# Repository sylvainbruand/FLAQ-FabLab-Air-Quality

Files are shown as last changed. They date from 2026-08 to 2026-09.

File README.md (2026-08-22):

# FLAQ XIAO — FabLab Air Quality

Projet académique de contrôle de la qualité de l’air dans les FabLabs, réalisé
avec une **Seeed Studio XIAO ESP32S3**. La carte acquiert les
capteurs, affiche les mesures sur OLED, enregistre l’historique sur microSD et
héberge elle-même un dashboard accessible depuis un téléphone ou un ordinateur.

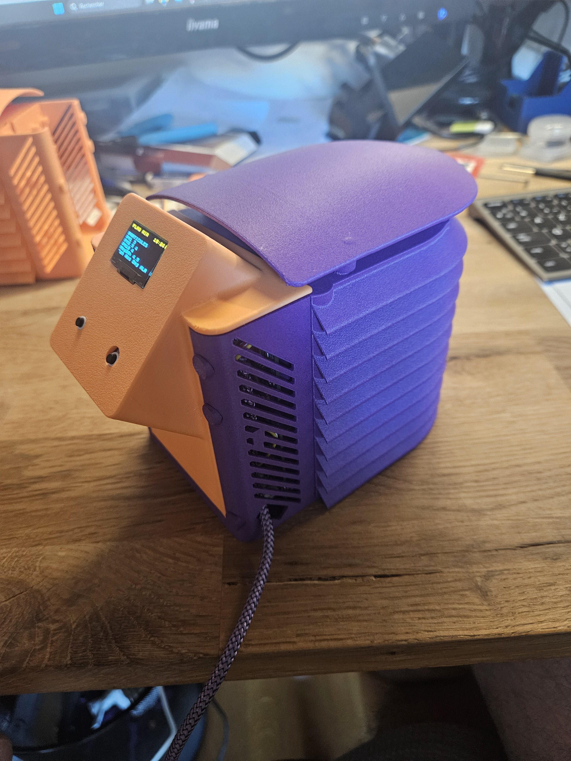
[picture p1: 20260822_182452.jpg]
Prototype FLAQ XIAO assemblé


## Fonctions incluses

- actualisation des mesures toutes les 10 secondes ;
- lecture du SGP40 toutes les secondes avec compensation DHT20 ;
- trois graphiques avec axes indépendants ;
- moyenne glissante PM2.5 sur 24 heures ;
- indice intérieur FLAQ du vert au rouge ;
- alarme confirmée sur buzzer passif au niveau rouge ;
- journal persistant des dépassements avec durée, moyenne et maximum ;
- synthèse quotidienne et export CSV depuis le dashboard ;
- horodatage par RTC Grove PCF85063 ;
- correction NTP automatique lorsque le réseau donne accès à Internet ;
- point d’accès `FLAQ-XIAO` si aucun Wi-Fi n’est configuré ou disponible ;
- reprise de l’historique des dernières 24 heures après redémarrage ;
- navigation manuelle entre les quatre pages OLED avec le bouton Grove ;
- extinction de l’OLED après 20 secondes sans appui et réveil automatique ;
- déclaration manuelle d’une ventilation avec un second bouton Grove ;
- signalement de la ventilation sur le dashboard ;
- bandes temporelles claires sur les graphes pendant les périodes ventilées.

## Matériel

| Fonction | Référence | Connexion |
|---|---|---|
| Carte | Seeed Studio XIAO ESP32S3 | — |
| Hub | Grove 8-Channel I²C Hub TCA9548A | `D4/SDA`, `D5/SCL`, adresse `0x70` |
| CO₂ | SCD30 | I²C `0x61` |
| Particules | HM3301 | I²C `0x40` |
| VOC | SGP40 | I²C `0x59` |
| HCHO indicatif | Grove HCHO WSP2110 | analogique `D0`, via pont diviseur |
| Température/humidité | DHT20 | I²C `0x38` |
| Horloge | RTC Grove PCF85063 | I²C `0x51` |
| Affichage | OLED SSD1306 128×64 | I²C `0x3C` |
| Alarme | Grove Passive Buzzer 107020109 | `D1` |
| Navigation OLED | Grove Button (P) 111020000 | port `D7 / UART` |
| Ventilation | Grove Button (P) 111020000 | port `D0 / A0` |
| Stockage | Adafruit MicroSD Breakout+ 254 | SPI, CS sur `D2` |

Le câblage détaillé se trouve dans
[ease_xiao/CABLAGE.md](ease_xiao/CABLAGE.md).

Au démarrage, le firmware ouvre automatiquement les huit canaux du TCA9548A.
Cette configuration est possible car chaque capteur utilise une adresse I²C
différente. Elle se règle avec `EASE_I2C_MUX_*` dans `config.example.h`.

## Préparation de l’Arduino IDE

1. Installer le paquet de cartes **esp32 by Espressif Systems**.
2. Sélectionner **XIAO_ESP32S3**.
3. Activer la PSRAM en mode **OPI PSRAM**.
4. Sélectionner une taille Flash de **8 MB**.
5. Installer les bibliothèques :
   - U8g2 ;
   - Adafruit SGP40 Sensor, avec ses dépendances ;
   - SparkFun SCD30 Arduino Library ;
   - DHT20 de Rob Tillaart.

Le HM3301 est lu directement par le firmware via `Wire`, afin d’éviter
l’incompatibilité du type `u32` présente dans la bibliothèque Seeed 1.0.2 avec
les versions ESP32 récentes. En cas de trame incomplète ou de checksum invalide,
la lecture est retentée trois fois et le capteur est automatiquement replacé en
mode I2C. Les concentrations utilisées sont les valeurs « environnement
atmosphérique » du HM3301.

Les bibliothèques `WiFi`, `WebServer`, `ESPmDNS`, `SD`, `SPI` et `Wire` sont
fournies par le paquet ESP32.

## Configuration Wi-Fi

Le projet fonctionne immédiatement sans identifiants : la carte crée le réseau
`FLAQ-XIAO`, protégé par le mot de passe `flaq-air`. Une fois connecté à ce
réseau, ouvrir `http://192.168.4.1`.

Pour connecter la station au réseau local :

1. copier `config.h.example` sous le nom `config.h` ;
2. renseigner le nom et le mot de passe Wi-Fi ;
3. téléverser à nouveau le programme.

Le dashboard devient alors accessible à l’adresse IP affichée sur l’OLED et,
si le réseau l’autorise, à `http://flaq-xiao.local`.

`config.h` est ignoré par Git pour ne pas publier le mot de passe.

## Carte microSD

Utiliser une microSD High Endurance de 32 Go formatée en FAT32. La station crée :

- `/data/AAAAMMJJ.csv` : mesures d’une journée ;
- `/events.csv` : dépassements terminés.

La fenêtre glissante est maintenue en PSRAM. Au redémarrage, les fichiers du
jour courant et du jour précédent sont relus afin de reconstruire les dernières
24 heures, la moyenne PM2.5 et les périodes de ventilation. La colonne
`ventilation` vaut `1` lorsque la fenêtre ou la porte a été déclarée ouverte.

## Seuils

Tous les seuils se trouvent dans `config.example.h` et peuvent être redéfinis
dans `config.h`. L’indice global correspond au paramètre instantané le plus
défavorable parmi CO₂, VOC, HCHO estimé, PM2.5 et PM10.

Une alerte ou un événement nécessite trois mesures consécutives au-dessus du
seuil. Le retour utilise un seuil plus bas et trois confirmations, ce qui évite
les oscillations autour d’une limite.

Le seuil de la moyenne PM2.5 sur 24 heures produit un événement distinct. Il
n’est activé que lorsque la station dispose d’au moins 23 heures d’historique.

Ces seuils constituent un indicateur pédagogique FLAQ de qualité de l’air
intérieur ; ils ne remplacent pas un dispositif réglementaire ou certifié.

## Particularités du WSP2110

Le WSP2110 est désactivé par défaut avec `EASE_WSP2110_ENABLED 0`. Dans cet
état, D0 n'est pas lu, le dashboard affiche « non installé », le HCHO est
ignoré par l'indice et aucune alerte HCHO n'est créée. Quand le capteur et son
pont diviseur sont prêts, définir `EASE_WSP2110_ENABLED 1` dans `config.h`.

Le WSP2110 est un capteur MOS sensible à plusieurs gaz et solvants. La valeur
« HCHO estimé » en ppm sert donc à suivre une tendance après étalonnage ; ce
n’est pas une mesure sélective ou certifiée du formaldéhyde. Le capteur demande
au moins 120 heures de préchauffage avant son étalonnage initial.

Le module Grove fonctionne en 5 V alors que l’entrée analogique du XIAO est en
3,3 V. Sa sortie doit obligatoirement passer par le pont 10 kΩ / 20 kΩ décrit
dans `ease_xiao/CABLAGE.md`. La constante `EASE_WSP2110_R0_RATIO` doit ensuite
être ajustée dans `config.h` avec la valeur obtenue en air propre stabilisé. Le
moniteur série affiche `WSP_Rs` et `ADC` pour faciliter cette opération.

## API embarquée

| Route | Rôle |
|---|---|
| `/` | dashboard |
| `/logo.png` | logo FLAQ et favicon |
| `/api/live` | dernière mesure et état technique |
| `/api/history?since=...&max=900` | historique sous-échantillonné |
| `/api/events?max=200` | journal des dépassements |
| `/api/events.csv` | téléchargement CSV |
| `/api/health` | mémoire et disponibilité du serveur |

## Organisation du dépôt

- [`ease_xiao/`](ease_xiao/) : station autonome XIAO ESP32S3 ;
- [`ease_station_test/`](ease_station_test/) : versions précédentes et station de test.

## Fichiers du projet XIAO

- `ease_xiao/ease_xiao.ino` : firmware complet ;
- `ease_xiao/dashboard.h` : interface web embarquée sans dépendance Internet ;
- `ease_xiao/config.example.h` : valeurs par défaut et seuils ;
- `ease_xiao/config.h.example` : modèle de configuration Wi-Fi ;
- `ease_xiao/CABLAGE.md` : raccordement pas à pas ;
- `ease_xiao/VERIFICATION.md` : procédure de mise en service.

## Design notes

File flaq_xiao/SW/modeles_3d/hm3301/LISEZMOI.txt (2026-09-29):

Modèle d'encombrement Grove HM3301 — Seeed v1.0

Sources :
https://wiki.seeedstudio.com/Grove-Laser_PM2.5_Sensor-HM3301/
Archive Eagle officielle conservée dans sources_seeed.zip.
Fiche HM-3300&3600_V2.1.pdf, dimensions du capteur : 40 x 38 x 15 mm.

Données issues du fichier Eagle : carte 80 x 40 mm, angles R3, quatre trous diamètre 3,2 mm aux coordonnées (+/-36,+/-16) ; trous de fixation capteur diamètre 2,4 mm à (-23,622,-17,018) et (12,573,17,145). Positions des composants et connecteurs issues du PCB.

Hypothèses à vérifier : PCB épaisseur 1,6 mm ; dessous capteur à 3,6 mm du dessous PCB ; hauteurs des connecteurs et composants ; grilles, capot, dégagements et vis simplifiés. Câble souple non représenté. Ne pas utiliser les grilles comme plan de fabrication ou pour une simulation de débit.

Pièce native SolidWorks 2025, fonctions éditables. Unités géométriques : mm (API en mètres). Fichier destiné à l'intégration mécanique ; contrôler les hauteurs sur l'exemplaire physique avant fabrication.

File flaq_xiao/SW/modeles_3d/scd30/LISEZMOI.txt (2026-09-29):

Grove SCD30 — modèle SolidWorks 2025

Sources :
https://wiki.seeedstudio.com/Grove-CO2_Temperature_Humidity_Sensor-SCD30/
https://sensirion.com/media/documents/E9438033/61653143/Sensirion_CO2_Sensors_SCD30_POD_STEP_File.zip

Capteur nu : 25 corps importés du STEP officiel Sensirion, sans modification de forme. Position de montage estimée.
Carte : contour et perçages issus du package GROVE-60X40MM du fichier Eagle Seeed. Débordements des oreilles compris : environ 64,2 x 44,2 mm, différents des dimensions générales 61 x 42 mm affichées au wiki. Le contour du fichier CAO est retenu. Epaisseur PCB supposée 1,6 mm.
Capot : contour repris du dessin de sérigraphie Seeed ; hauteur, épaisseur, ouvertures et vis simplifiées/estimées. Hauteur totale fixée à 19 mm selon la fiche générale. Connecteur Grove placé selon Eagle ; hauteur simplifiée.

Pièce mult icorps native SLDPRT : formes importées Sensirion et fonctions éditables pour la carte, le connecteur et le capot. Aucune dépendance externe nécessaire à l'ouverture du SLDPRT. Vérifier les dimensions de votre révision physique avant fabrication d'un boîtier.

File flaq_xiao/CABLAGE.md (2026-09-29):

# Câblage de la station FLAQ XIAO

## Bus I²C Grove

Raccorder le Grove 8-Channel I²C Hub TCA9548A au port I²C du Grove Shield XIAO :

- SDA : `D4 / GPIO5` ;
- SCL : `D5 / GPIO6` ;
- alimentation et masse communes.

Brancher ensuite sur le hub : SCD30, HM3301, SGP40, DHT20, OLED et RTC
PCF85063. Leurs adresses sont différentes ; aucun multiplexeur logiciel n’est
nécessaire par capteur. Le firmware écrit `0xFF` à l’adresse `0x70` au démarrage
pour ouvrir simultanément les huit canaux du TCA9548A.

La longueur totale des câbles I²C doit rester raisonnable. Le firmware utilise
100 kHz pour améliorer la robustesse avec plusieurs modules.

## Buzzer Grove 107020109

Brancher le buzzer passif sur le port numérique correspondant à `D1`. Le
firmware produit une tonalité de 2 700 Hz lorsque l’indice rouge est confirmé.

## Grove Dual Button sur D7 / UART

Raccorder le Grove Dual Button au connecteur marqué `D7 / UART` du shield
XIAO. Les deux lignes de signal de cette prise sont utilisées :

| Signal Grove | XIAO ESP32S3 | Fonction |
|---|---|---|
| jaune / SIG1 | `D7` | bouton de changement de page |
| blanc / SIG2 | `D6` | bouton de ventilation |
| rouge | `3,3 V` | alimentation du Dual Button |
| noir | `GND` | masse |

Le bouton sur D7 fait avancer d’une page et la quatrième page revient à la première.
L’écran s’éteint après 20 secondes sans appui ; l’appui suivant le rallume et
affiche directement la page suivante. Le filtrage anti-rebond est intégré au
firmware.

Le bouton sur D6 inverse l’état : ventilation active, puis ventilation arrêtée.
Un appui simultané sur les deux boutons active ou désactive le mode muet.
Les sorties du module sont actives à l’état bas ; le firmware active aussi les
résistances de tirage internes de la XIAO.

Le Dual Button doit être alimenté ici en 3,3 V afin que ses niveaux hauts restent
sans danger pour la XIAO. Ne jamais envoyer directement un signal 5 V sur D6 ou
D7. Ce raccordement laisse `D0 / A0` entièrement disponible pour le WSP2110.

## Grove HCHO WSP2110 — entrée analogique protégée

Le WSP2110 n’est pas raccordé au hub I²C. Alimenter son module Grove en 5 V et
relier toutes les masses. Sa sortie analogique peut dépasser 3,3 V : ne jamais
la brancher directement sur `D0` du XIAO.

Réaliser ce pont diviseur :

```text
Sortie SIG du WSP2110 ── 10 kΩ ──┬── D0 du XIAO
                                  │
                                 20 kΩ
                                  │
                                 GND
```

Ajouter de préférence un condensateur céramique de 100 nF entre `D0` et GND,
au plus près du XIAO. Le rapport du pont est alors 2/3, valeur déjà définie par
`FLAQ_WSP2110_DIVIDER_RATIO`. Vérifier au multimètre que D0 reste toujours sous
3,3 V avant de le connecter à la carte.

Le firmware accepte que le WSP2110 ne soit pas installé : D0 peut rester non
connecté, le démarrage continue normalement et la valeur HCHO reste indiquée
comme indisponible jusqu’à la première lecture valide. Un bref test logiciel
compare les résistances de tirage vers la masse et vers le 3,3 V afin d’empêcher
une entrée D0 flottante d’être prise par erreur pour un capteur présent. Trois
lectures valides consécutives sont ensuite nécessaires pour publier le HCHO.

## Module microSD Adafruit 254

| Adafruit 254 | XIAO ESP32S3 | Fonction |
|---|---|---|
| `5V` | `5V/VBUS` | alimentation du régulateur du module |
| `GND` | `GND` | masse commune |
| `CLK` | `D8 / GPIO7` | horloge SPI |
| `DO` | `D9 / GPIO8` | MISO |
| `DI` | `D10 / GPIO9` | MOSI |
| `CS` | `D2 / GPIO3` | sélection de la carte |

Le raccordement `5V/VBUS` suppose une alimentation USB 5 V. Pour une station
alimentée uniquement par batterie, vérifier que le rail 5 V reste disponible
ou prévoir une alimentation adaptée pour le module microSD et les capteurs.

## Alimentation

Le HM3301 et le SCD30 contiennent des éléments actifs et le HM3301 possède un
ventilateur. Employer une alimentation USB 5 V stable, avec une marge de
courant suffisante. Toutes les masses doivent être communes.

Ne jamais appliquer un signal ou une tension analogique 5 V directement aux GPIO de la XIAO.
L’Adafruit 254 réalise l’adaptation nécessaire pour la microSD.

## Implantation des capteurs

- éloigner le DHT20 de la chaleur produite par la XIAO et le régulateur ;
- ne pas placer les entrées d’air du SCD30, du HM3301 et du WSP2110 contre une paroi ;
- éviter que la sortie d’air du HM3301 souffle directement sur le DHT20 ;
- laisser le SGP40 exposé au même volume d’air que les autres capteurs ;
- éloigner le WSP2110 des vapeurs de solvants et garder son module sous tension
  au moins 120 heures avant l’étalonnage initial ;
- conserver le buzzer et l’OLED hors du trajet principal de l’air.

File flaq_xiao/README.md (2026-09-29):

# FLAQ XIAO — FabLab Air Quality

Projet académique de contrôle de la qualité de l’air dans les FabLabs, réalisé
avec une **Seeed Studio XIAO ESP32S3**. La carte acquiert les
capteurs, affiche les mesures sur OLED, enregistre l’historique sur microSD et
héberge elle-même un dashboard accessible depuis un téléphone ou un ordinateur.

## Fonctions incluses

- actualisation des mesures toutes les 10 secondes ;
- lecture du SGP40 toutes les secondes avec compensation DHT20 ;
- trois graphiques avec axes indépendants ;
- moyenne glissante PM2.5 sur 24 heures ;
- indice intérieur FLAQ du vert au rouge ;
- alarme confirmée sur buzzer passif au niveau rouge ;
- journal persistant des dépassements avec durée, moyenne et maximum ;
- synthèse quotidienne et export CSV depuis le dashboard ;
- horodatage par RTC Grove PCF85063 ;
- correction NTP automatique lorsque le réseau donne accès à Internet ;
- point d’accès `FLAQ-XIAO` si aucun Wi-Fi n’est configuré ou disponible ;
- reprise de l’historique des dernières 24 heures après redémarrage.
- navigation manuelle entre les quatre pages OLED avec le bouton Grove ;
- extinction de l’OLED après 20 secondes sans appui et réveil automatique.
- déclaration manuelle d’une ventilation avec un second bouton Grove ;
- mode mute basculé en appuyant sur les deux boutons en même temps ;
- signalement de la ventilation sur le dashboard et éclaircissement des graphes.
- bandes temporelles claires sur les graphes pendant les périodes ventilées.

## Matériel

| Fonction | Référence | Connexion |
|---|---|---|
| Carte | Seeed Studio XIAO ESP32S3 | — |
| Hub | Grove 8-Channel I²C Hub TCA9548A | `D4/SDA`, `D5/SCL`, adresse `0x70` |
| CO₂ | SCD30 | I²C `0x61` |
| Particules | HM3301 | I²C `0x40` |
| VOC | SGP40 | I²C `0x59` |
| HCHO indicatif | Grove HCHO WSP2110 | analogique `D0`, via pont diviseur |
| Température/humidité | DHT20 | I²C `0x38` |
| Horloge | RTC Grove PCF85063 | I²C `0x51` |
| Affichage | OLED SSD1306 128×64 | I²C `0x3C` |
| Alarme | Grove Passive Buzzer 107020109 | `D1` |
| Navigation OLED + ventilation | Grove Dual Button | port `D7 / UART` (`D7` + `D6`) |
| Stockage | Adafruit MicroSD Breakout+ 254 | SPI, CS sur `D2` |

Le câblage détaillé se trouve dans [CABLAGE.md](CABLAGE.md).

Au démarrage, le firmware ouvre automatiquement les huit canaux du TCA9548A.
Cette configuration est possible car chaque capteur utilise une adresse I²C
différente. Elle se règle avec `FLAQ_I2C_MUX_*` dans `config.example.h`.

## Préparation de l’Arduino IDE

1. Installer le paquet de cartes **esp32 by Espressif Systems**.
2. Sélectionner **XIAO_ESP32S3**.
3. Activer la PSRAM en mode **OPI PSRAM**.
4. Sélectionner une taille Flash de **8 MB**.
5. Installer les bibliothèques :
   - U8g2 ;
   - Adafruit SGP40 Sensor, avec ses dépendances ;
   - SparkFun SCD30 Arduino Library ;
   - DHT20 de Rob Tillaart.

Le HM3301 est lu directement par le firmware via `Wire`, afin d’éviter
l’incompatibilité du type `u32` présente dans la bibliothèque Seeed 1.0.2 avec
les versions ESP32 récentes. En cas de trame incomplète ou de checksum invalide,
la lecture est retentée trois fois et le capteur est automatiquement replacé en
mode I2C. Les concentrations utilisées sont les valeurs « environnement
atmosphérique » du HM3301.

Les bibliothèques `WiFi`, `WebServer`, `ESPmDNS`, `SD`, `SPI` et `Wire` sont
fournies par le paquet ESP32.

## Configuration Wi-Fi

Le projet fonctionne immédiatement sans identifiants : la carte crée le réseau
`FLAQ-XIAO`, protégé par le mot de passe `flaq-air`. Une fois connecté à ce
réseau, ouvrir `http://192.168.4.1`.

Pour connecter la station au réseau local :

1. copier `config.h.example` sous le nom `config.h` ;
2. renseigner les noms et mots de passe des réseaux Wi-Fi dans
   `FLAQ_WIFI_NETWORKS` (une ligne par réseau) ;
3. téléverser à nouveau le programme.

Au démarrage, l’OLED affiche la liste configurée. Le bouton sur D7 passe au
réseau suivant et le bouton sur D6 valide le réseau affiché. Après la
validation, les deux boutons reprennent automatiquement leur fonctionnement
normal (pages OLED et ventilation). Si la connexion choisie échoue, la station
crée comme auparavant le point d’accès `FLAQ-XIAO`.

Le dashboard devient alors accessible à l’adresse IP affichée sur l’OLED et,
si le réseau l’autorise, à `http://flaq-xiao.local`.

`config.h` est ignoré par Git pour ne pas publier le mot de passe.

## Carte microSD

Utiliser une microSD High Endurance de 32 Go formatée en FAT32. La station crée :

- `/data/AAAAMMJJ.csv` : mesures d’une journée ;
- `/events.csv` : dépassements terminés.

La fenêtre glissante est maintenue en PSRAM. Au redémarrage, les fichiers du
jour courant et du jour précédent sont relus afin de reconstruire les dernières
24 heures, la moyenne PM2.5 et les périodes de ventilation. La colonne
`ventilation` vaut `1` lorsque la fenêtre ou la porte a été déclarée ouverte.

## Seuils

Tous les seuils se trouvent dans `config.example.h` et peuvent être redéfinis
dans `config.h`. L’indice global correspond au paramètre instantané le plus
défavorable parmi CO₂, VOC, HCHO estimé, PM2.5 et PM10.

Une alerte ou un événement nécessite trois mesures consécutives au-dessus du
seuil. Le retour utilise un seuil plus bas et trois confirmations, ce qui évite
les oscillations autour d’une limite.

Le seuil de la moyenne PM2.5 sur 24 heures produit un événement distinct. Il
n’est activé que lorsque la station dispose d’au moins 23 heures d’historique.

Ces seuils constituent un indicateur pédagogique FLAQ de qualité de l’air
intérieur ; ils ne remplacent pas un dispositif réglementaire ou certifié.

## Particularités du WSP2110

Le WSP2110 est lu sur D0 mais reste optionnel. S’il n’est pas branché, ou tant
qu’aucune lecture valide n’est détectée, le dashboard affiche « indisponible »,
le HCHO est ignoré par l’indice et aucune alerte HCHO n’est créée. Cette absence
n’empêche ni le démarrage ni le fonctionnement des autres capteurs.

Le WSP2110 est un capteur MOS sensible à plusieurs gaz et solvants. La valeur
« HCHO estimé » en ppm sert donc à suivre une tendance après étalonnage ; ce
n’est pas une mesure sélective ou certifiée du formaldéhyde. Le capteur demande
au moins 120 heures de préchauffage avant son étalonnage initial.

Le module Grove fonctionne en 5 V alors que l’entrée analogique du XIAO est en
3,3 V. Sa sortie doit obligatoirement passer par le pont 10 kΩ / 20 kΩ décrit
dans `CABLAGE.md`. La constante `FLAQ_WSP2110_R0_RATIO` doit ensuite être
ajustée dans `config.h` avec la valeur obtenue en air propre stabilisé. Le
moniteur série affiche `WSP_Rs` et `ADC` pour faciliter cette opération.

## API embarquée

| Route | Rôle |
|---|---|
| `/` | dashboard |
| `/logo.png` | logo FLAQ et favicon |
| `/api/live` | dernière mesure et état technique |
| `/api/history?since=...&max=900` | historique sous-échantillonné |
| `/api/events?max=200` | journal des dépassements |
| `/api/events.csv` | téléchargement CSV |
| `/api/health` | mémoire et disponibilité du serveur |

## Fichiers du projet

- `flaq_xiao.ino` : firmware complet ;
- `dashboard.h` : interface web embarquée sans dépendance Internet ;
- `flaq_logo.png` et `flaq_logo.h` : logo optimisé et ressource embarquée ;
- `config.example.h` : valeurs par défaut et seuils ;
- `config.h.example` : modèle de configuration Wi-Fi ;
- `CABLAGE.md` : raccordement pas à pas ;
- `VERIFICATION.md` : procédure de mise en service.

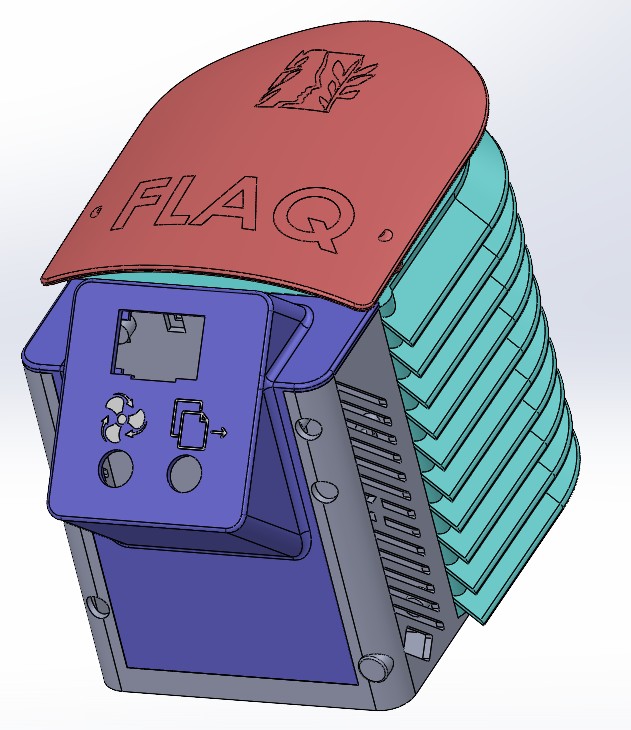
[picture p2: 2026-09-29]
Flaq_SW.jpg

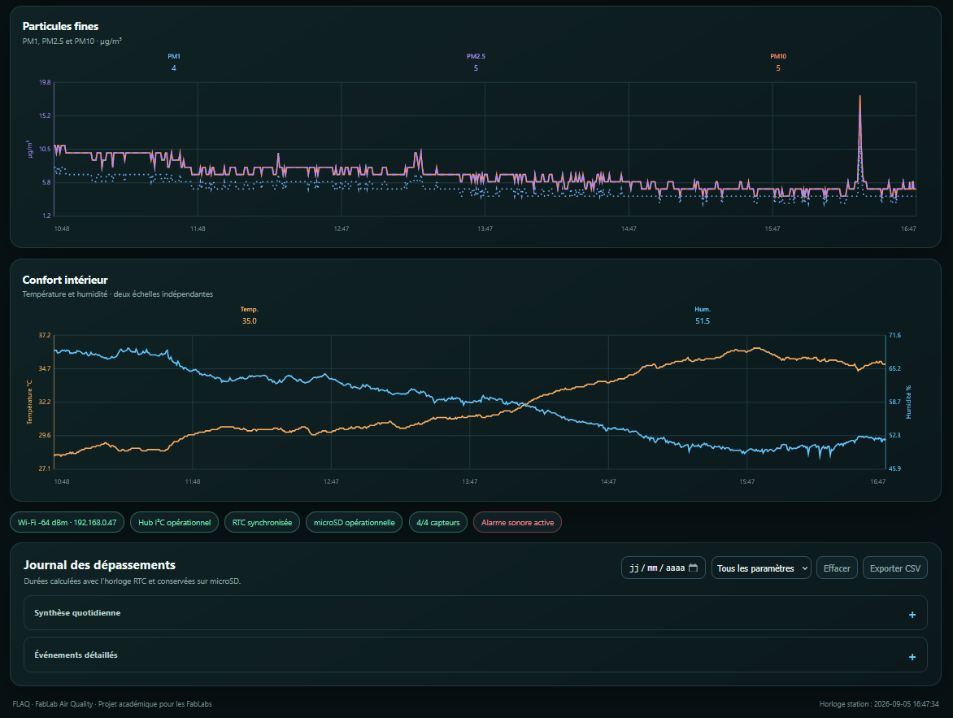
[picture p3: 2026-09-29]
flaq_xiao/FLAQ-2.png

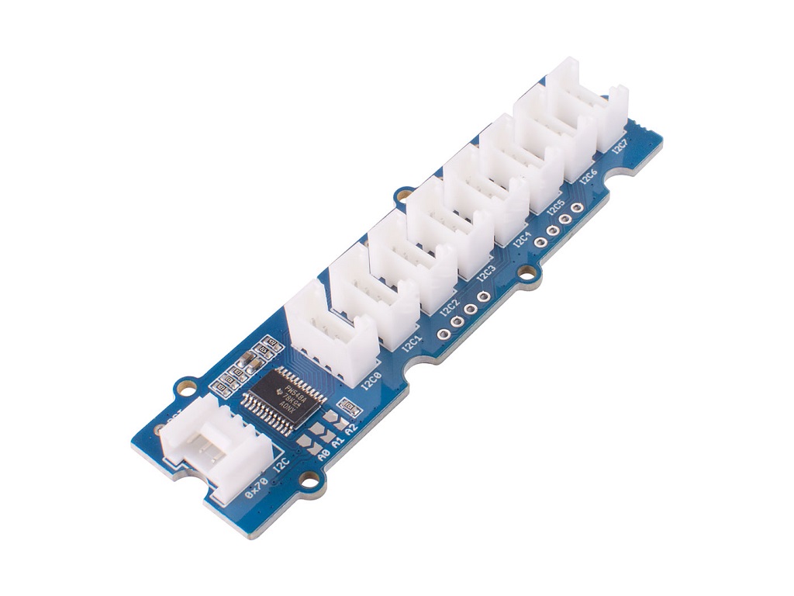
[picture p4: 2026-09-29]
flaq_xiao/SW/modeles_3d/grove_8_ports/reference.jpg

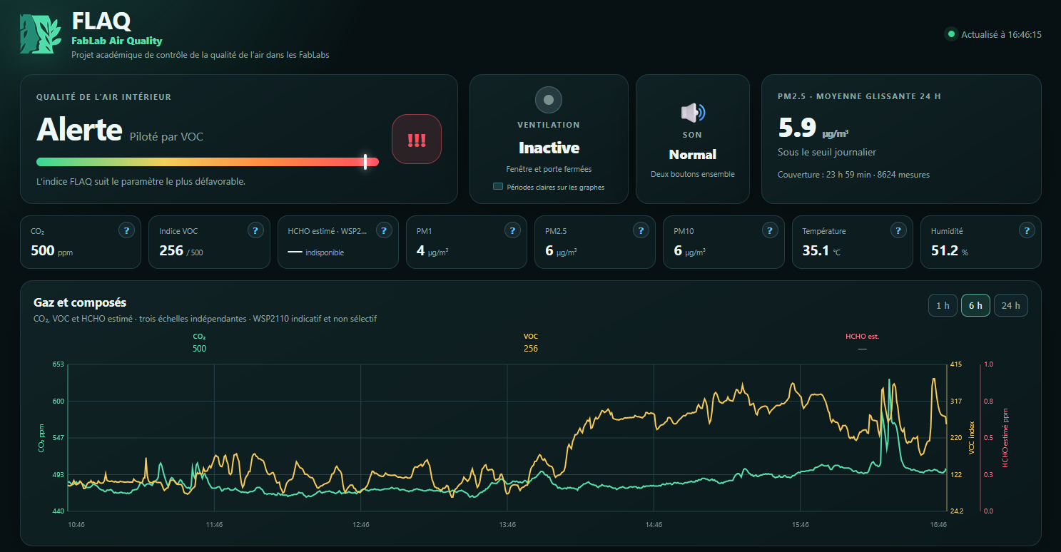
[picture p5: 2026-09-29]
flaq_xiao/FLAQ-1.png

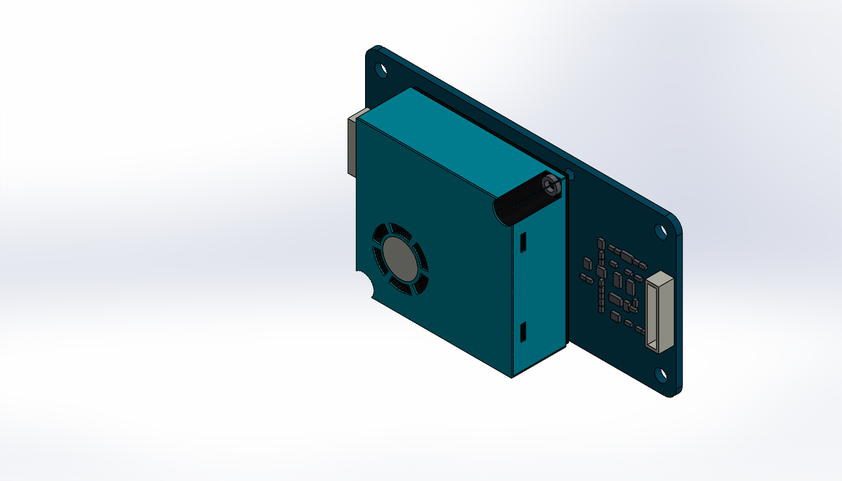
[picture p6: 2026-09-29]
flaq_xiao/SW/modeles_3d/hm3301/apercu.bmp

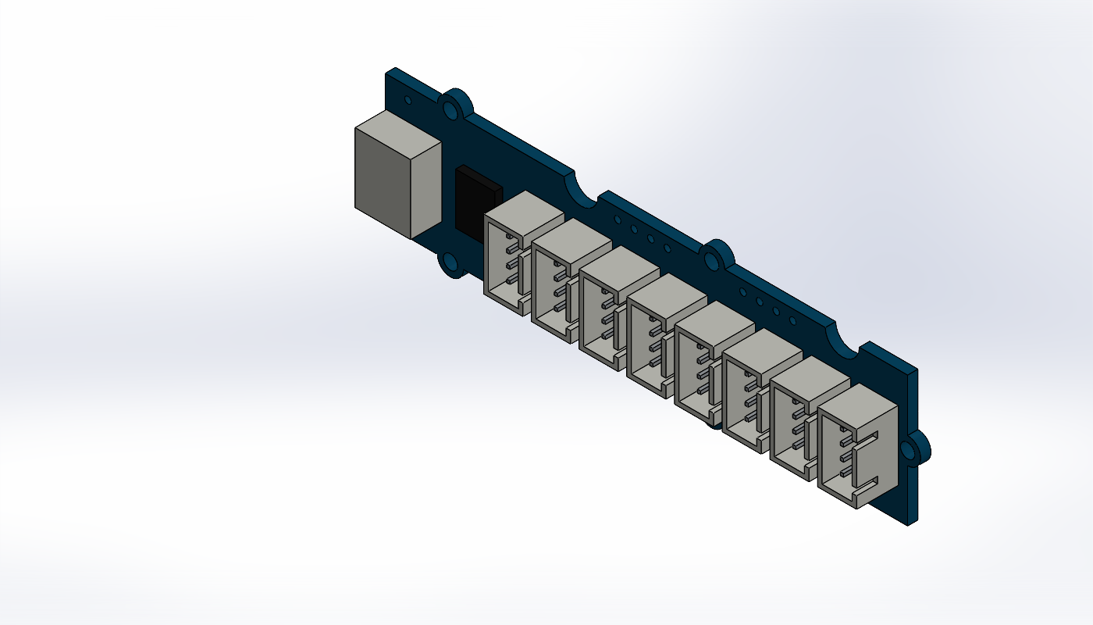
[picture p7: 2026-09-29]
flaq_xiao/SW/modeles_3d/grove_8_ports/apercu.bmp

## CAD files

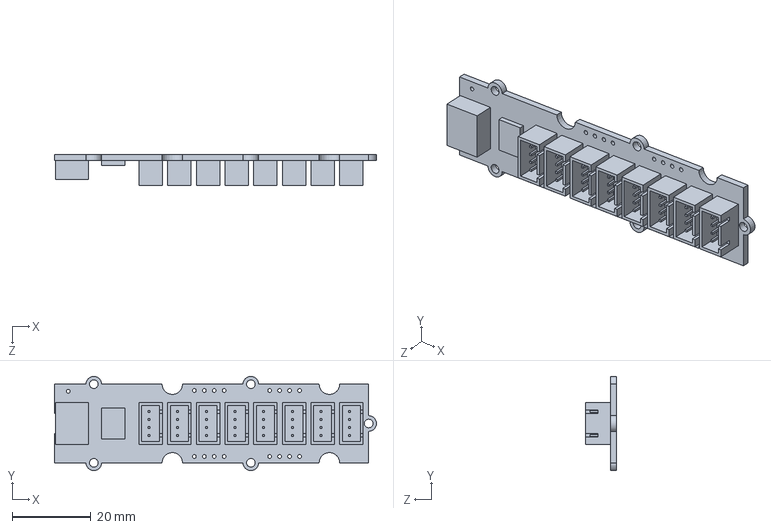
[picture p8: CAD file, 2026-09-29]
flaq_xiao/SW/modeles_3d/grove_8_ports/Grove_8_ports_TCA9548A_ESTIME.SLDPRT
82.0 x 24.0 x 8.00 mm

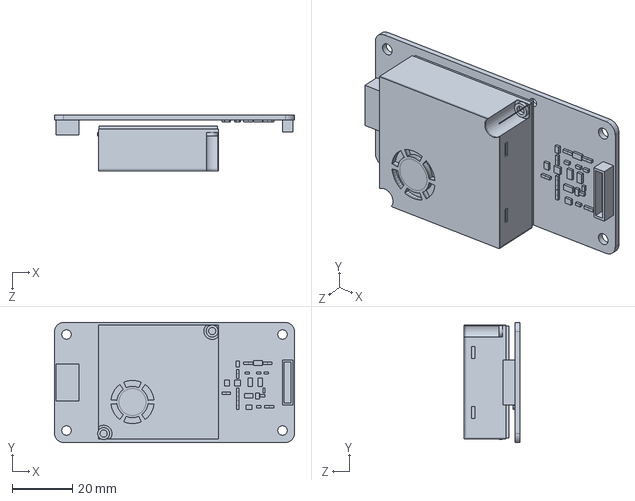
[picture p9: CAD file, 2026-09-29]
flaq_xiao/SW/modeles_3d/hm3301/Grove_HM3301.SLDPRT
80.0 x 40.0 x 18.6 mm

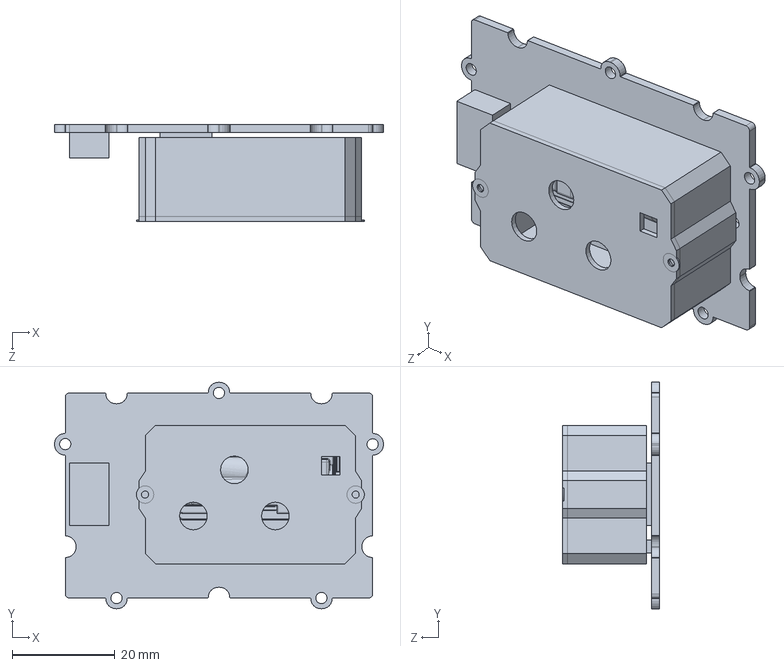
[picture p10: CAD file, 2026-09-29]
flaq_xiao/SW/modeles_3d/scd30/Grove_SCD30.SLDPRT
64.2 x 44.2 x 19.0 mm

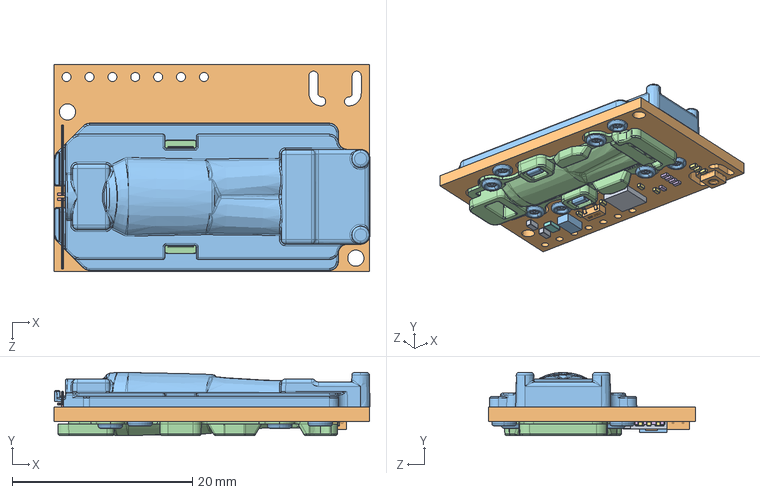
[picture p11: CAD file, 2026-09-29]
flaq_xiao/SW/modeles_3d/scd30/sensirion_cad/Sensirion_CO2_Sensors_SCD30_POD_STEP_File.step
35.1 x 7.00 x 23.0 mm

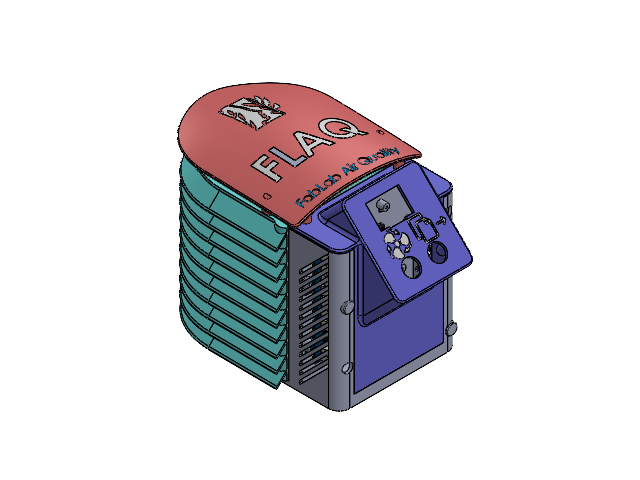
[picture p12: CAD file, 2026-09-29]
flaq_xiao/SW/ensemble_xiao.SLDASM
boitier bas
etage stevenson
couvercle_xiao
logo_BP_xiao
bouchon
bouchon2
toit_xiao_V2
Grove Connector (standing).step x 8
FemaleHeader.step x 2
eBom-FreeParts.step x 2
BOSS-EXTRUDE14_8_.step
BOSS-EXTRUDE7_4_.step
BOSS-EXTRUDE7_3_.step
BOSS-EXTRUDE14_4_.step
BOSS-EXTRUDE14_2_.step
BOSS-EXTRUDE14_11_.step
BOSS-EXTRUDE7_7_.step
BOSS-EXTRUDE14_9_.step
BOSS-EXTRUDE14_3_.step
BOSS-EXTRUDE14_7_.step
MIRROR2.step
BOSS-EXTRUDE14_5_.step
BOSS-EXTRUDE14_12_.step
BOSS-EXTRUDE7_8_.step
BOSS-EXTRUDE7_1_.step
BOSS-EXTRUDE14_10_.step
BOSS-EXTRUDE7_9_.step
BOSS-EXTRUDE14_6_.step
CHAMFER9.step
BOSS-EXTRUDE14_1_.step
BOSS-EXTRUDE7_6_.step
BOSS-EXTRUDE7_2_.step
CUT-EXTRUDE5.step
BOSS-EXTRUDE7_5_.step
Body.step x 2
Pins.step x 2
DF40C-30DP-0.4V_51_ v1.step
Shield.step
U.FL-R-SMT-1_10_ v1.step
XIAO ESP32S3 PLUS_V1.0_241025_PCB-0.step
XIAO ESP32S3 PLUS_V1.0_241025_PCB-1.step
XIAO ESP32S3 PLUS_V1.0_241025_PCB-2.step
XIAO ESP32S3 PLUS_V1.0_241025_PCB-3.step
XIAO ESP32S3 PLUS_V1.0_241025_PCB-4.step
XIAO ESP32S3 PLUS_V1.0_241025_PCB-5.step
XIAO ESP32S3 PLUS_V1.0_241025_PCB-6.step
XIAO ESP32S3 PLUS_V1.0_241025_PCB-7.step
XIAO ESP32S3 PLUS_V1.0_241025_PCB-8.step
XIAO ESP32S3 PLUS_V1.0_241025_PCB-9.step
XIAO ESP32S3 PLUS_V1.0_241025_PCB-10.step
XIAO ESP32S3 PLUS_V1.0_241025_PCB-11.step
XIAO ESP32S3 PLUS_V1.0_241025_PCB-12.step
XIAO ESP32S3 PLUS_V1.0_241025_PCB-13.step
XIAO ESP32S3 PLUS_V1.0_241025_PCB-14.step
XIAO ESP32S3 PLUS_V1.0_241025_PCB-15.step
XIAO ESP32S3 PLUS_V1.0_241025_PCB-16.step
XIAO ESP32S3 PLUS_V1.0_241025_PCB-17.step
XIAO ESP32S3 PLUS_V1.0_241025_PCB-18.step
XIAO ESP32S3 PLUS_V1.0_241025_PCB-19.step
XIAO ESP32S3 PLUS_V1.0_241025_PCB-20.step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

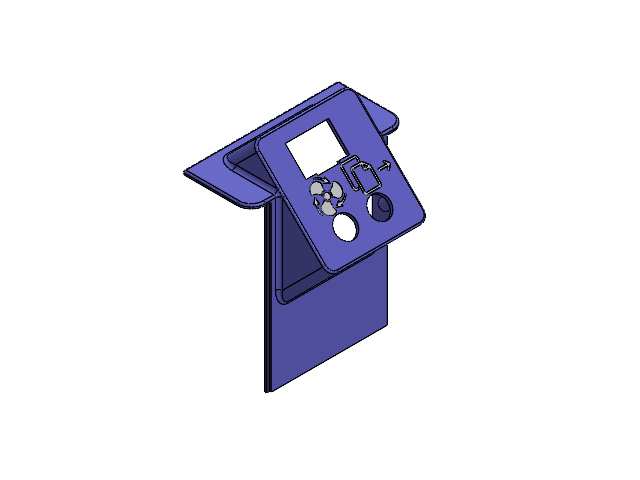
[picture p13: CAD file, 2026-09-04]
flaq_xiao/SW/ensemble_couvercle_xiao.SLDASM
couvercle_xiao
logo_BP_xiao

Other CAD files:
flaq_xiao/SW/USB TYPE C PORT.step.SLDASM
flaq_xiao/SW/XIAO ESP32S3 PLUS v4.step.SLDASM
flaq_xiao/SW/SKTAAAE010 v1.step.SLDASM
flaq_xiao/SW/XIAO ESP32S3 PLUS_V1.0_241025 1.step.SLDASM
flaq_xiao/SW/XIAO ESP32S3 PLUS_V1.0_241025_PCB.step.SLDASM
flaq_xiao/SW/USB TYPE C PORT (1).step.SLDASM
flaq_xiao/SW/XIAO ESP32S3 PLUS_V1.0_241025_PCB-6.step.SLDPRT
flaq_xiao/SW/XIAO ESP32S3 PLUS_V1.0_241025_PCB-20.step.SLDPRT
flaq_xiao/SW/XIAO ESP32S3 PLUS_V1.0_241025_PCB-17.step.SLDPRT
flaq_xiao/SW/CHAMFER9.step.SLDPRT
flaq_xiao/SW/BOSS-EXTRUDE14_9_.step.SLDPRT
flaq_xiao/SW/BOSS-EXTRUDE14_8_.step.SLDPRT
flaq_xiao/SW/BOSS-EXTRUDE14_10_.step.SLDPRT
flaq_xiao/SW/BOSS-EXTRUDE14_11_.step.SLDPRT
flaq_xiao/SW/BOSS-EXTRUDE14_12_.step.SLDPRT
flaq_xiao/SW/BOSS-EXTRUDE14_1_.step.SLDPRT
flaq_xiao/SW/BOSS-EXTRUDE14_2_.step.SLDPRT
flaq_xiao/SW/BOSS-EXTRUDE14_3_.step.SLDPRT
flaq_xiao/SW/BOSS-EXTRUDE14_4_.step.SLDPRT
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

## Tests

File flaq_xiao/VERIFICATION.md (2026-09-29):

# Vérification et mise en service

## Avant le premier démarrage

1. Contrôler toutes les alimentations et la masse commune.
2. Insérer une microSD 32 Go High Endurance formatée en FAT32.
3. Installer une pile fonctionnelle dans la RTC Grove.
4. Activer **OPI PSRAM** dans les options de la XIAO ESP32S3.
5. Téléverser `flaq_xiao.ino` et ouvrir le moniteur série à 115 200 bauds.
6. Avant de raccorder D0, mesurer la sortie du pont WSP2110 et confirmer
   qu’elle reste sous 3,3 V.

Tant que le WSP2110 et son pont diviseur ne sont pas montés, D0 peut rester
entièrement non connecté : le démarrage doit continuer et la mesure HCHO doit
rester indisponible.

## Démarrage attendu

Avec le WSP2110 absent, le moniteur série doit indiquer l’état des quatre
capteurs actifs, du hub TCA9548A, de la RTC, de la
microSD et du Wi-Fi. Le HM3301 demande environ 30 secondes de stabilisation. Le
SGP40 détecte rapidement les variations, mais ses performances nominales
nécessitent une période de fonctionnement plus longue. Le WSP2110 demande au
moins 120 heures de chauffe avant l’étalonnage initial ; avant cela, sa valeur
sert uniquement à vérifier que la chaîne analogique répond.

L’adresse `Adresse MAC Wi-Fi (STA)` affichée dans le moniteur série ne doit pas
être `00:00:00:00:00:00`. Avec D0 non branchée, le WSP2110 doit rester indiqué
comme indisponible.

Pour le HM3301, chaque acquisition est retentée jusqu'à trois fois. Après une
erreur, le firmware rouvre le TCA9548A et renvoie automatiquement la commande
I2C `0x88`. Le moniteur affiche `HM=1` lorsque la trame de 29 octets et son
checksum sont valides. Les valeurs PM employées sont celles prévues par le
HM3301 pour l'environnement atmosphérique.

Avant les messages des capteurs, le moniteur doit afficher :

```text
Hub I2C TCA9548A 0x70: OK (canaux 0xFF)
```

Sans configuration Wi-Fi :

1. se connecter au réseau `FLAQ-XIAO` ;
2. utiliser le mot de passe `flaq-air` ;
3. ouvrir `http://192.168.4.1`.

Avec configuration Wi-Fi, utiliser l’adresse affichée sur la quatrième page de
l’OLED. Au démarrage, vérifier que le bouton droit parcourt les réseaux
configurés, que le bouton sur D6 valide le réseau affiché, puis que les deux
boutons retrouvent leurs fonctions normales après la connexion.

## Contrôles fonctionnels

- les valeurs du dashboard changent toutes les 10 secondes ;
- le graphe gaz montre trois axes ;
- le graphe et la carte WSP2110 indiquent clairement « HCHO estimé » en ppm ;
- le graphe climat montre deux axes ;
- `/api/health` répond avec la mémoire libre ;
- la microSD contient le fichier quotidien dans `/data` ;
- le statut RTC et le statut microSD sont verts dans le dashboard ;
- après un redémarrage, l’historique récent réapparaît.

## Test des événements

Pour éviter d’exposer volontairement les capteurs à une pollution dangereuse,
faire le premier test avec des seuils temporairement abaissés dans `config.h`.
Vérifier qu’après trois mesures au-dessus du seuil :

- l’indice passe au rouge ;
- le buzzer émet son motif sonore ;
- l’événement reste actif jusqu’au retour sous le seuil de réarmement ;
- une ligne est ajoutée à `/events.csv` à la fin ;
- le dashboard affiche durée, moyenne et maximum.

Restaurer impérativement les seuils normaux après le test.

## Étalonnage indicatif du WSP2110

1. Laisser le module fonctionner au moins 120 heures dans un air propre et
   stable, sans solvants, alcool ni fumée à proximité.
2. Relever plusieurs valeurs `WSP_Rs` dans le moniteur série et calculer leur
   moyenne.
3. Copier `config.h.example` vers `config.h`, puis remplacer
   `FLAQ_WSP2110_R0_RATIO` par cette moyenne.
4. Téléverser à nouveau le firmware et contrôler la stabilité pendant plusieurs
   heures.

Cette calibration suit la courbe typique du module Grove. Le WSP2110 répond à
plusieurs composés organiques ; ne pas utiliser sa valeur comme mesure
réglementaire ou comme dispositif de sécurité.

## Diagnostic rapide

- **PSRAM ERREUR sur OLED** : activer OPI PSRAM dans l’IDE.
- **microSD indisponible** : vérifier FAT32, CS sur D2 et les quatre fils SPI.
- **RTC à vérifier** : contrôler la pile, l’adresse `0x51` et remettre l’heure
  par NTP ou au moyen d’un sketch de réglage.
- **dashboard inaccessible** : lire l’adresse IP sur l’OLED et vérifier que le
  téléphone ou le PC se trouve sur le même réseau.
- **un capteur manque** : débrancher temporairement les autres branches du hub
  et vérifier le capteur seul avec un scanner I²C.
- **WSP2110 absent ou valeur incohérente** : contrôler son alimentation 5 V, la
  masse commune, le pont 10 kΩ / 20 kΩ et les valeurs `ADC`/`WSP_Rs` du moniteur
  série ; ce capteur n’apparaît pas dans un scanner I²C.

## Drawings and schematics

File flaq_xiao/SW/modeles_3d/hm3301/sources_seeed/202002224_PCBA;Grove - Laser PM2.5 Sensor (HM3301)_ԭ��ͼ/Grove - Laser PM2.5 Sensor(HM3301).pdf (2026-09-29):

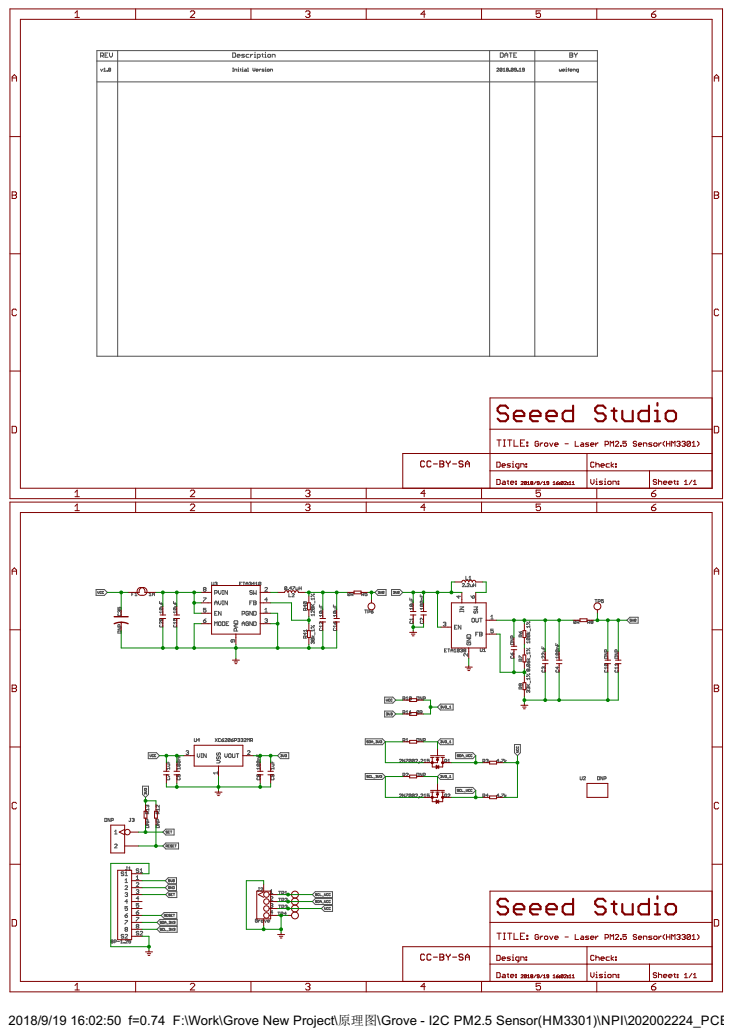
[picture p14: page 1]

2018/9/19 16:02:50 f=0.74 F:\Work\Grove New Project\原理图\Grove - I2C PM2.5 Sensor(HM3301)\NPI\202002224_PCBA;Grove - Laser PM2.5 Sensor (HM3301)_原理图\Grove - Laser PM2.5 Sensor(HM3301).sch (Sheet: 1/1)

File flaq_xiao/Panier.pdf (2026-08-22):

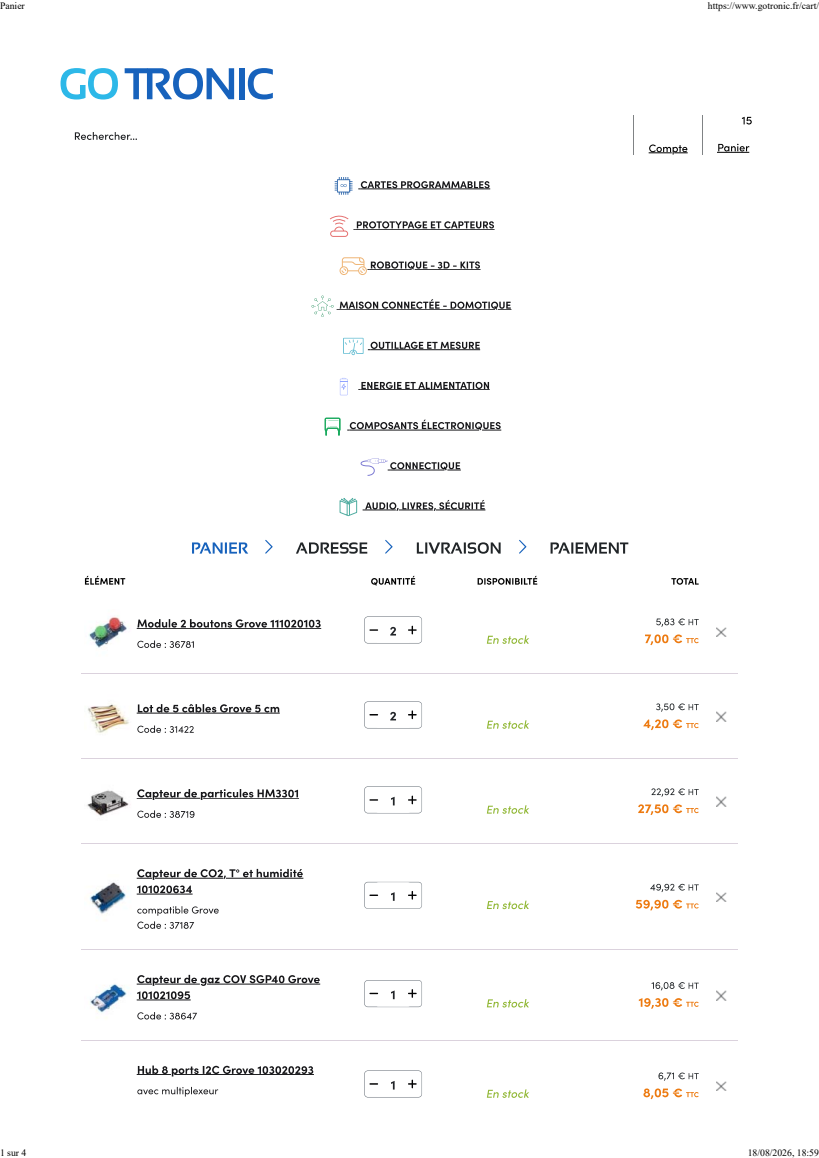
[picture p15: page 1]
Panier; https://www.gotronic.fr/cart/; 1 sur 4

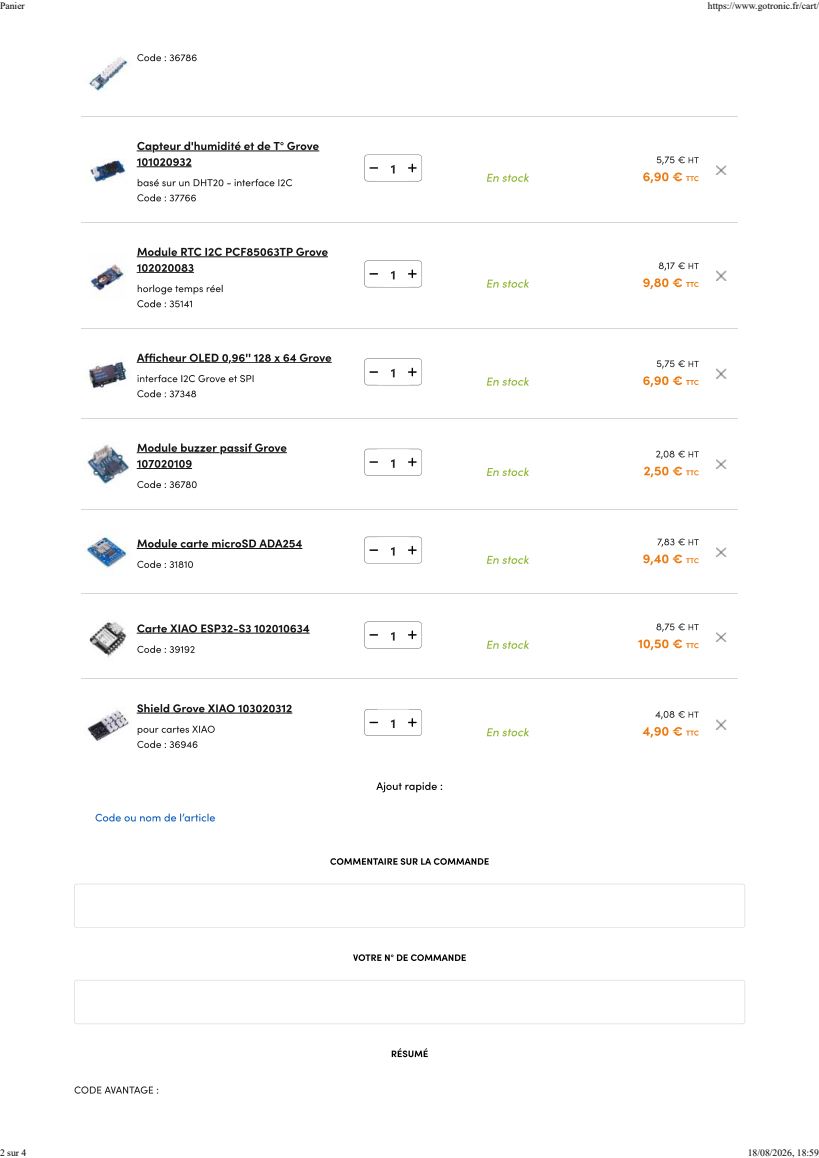
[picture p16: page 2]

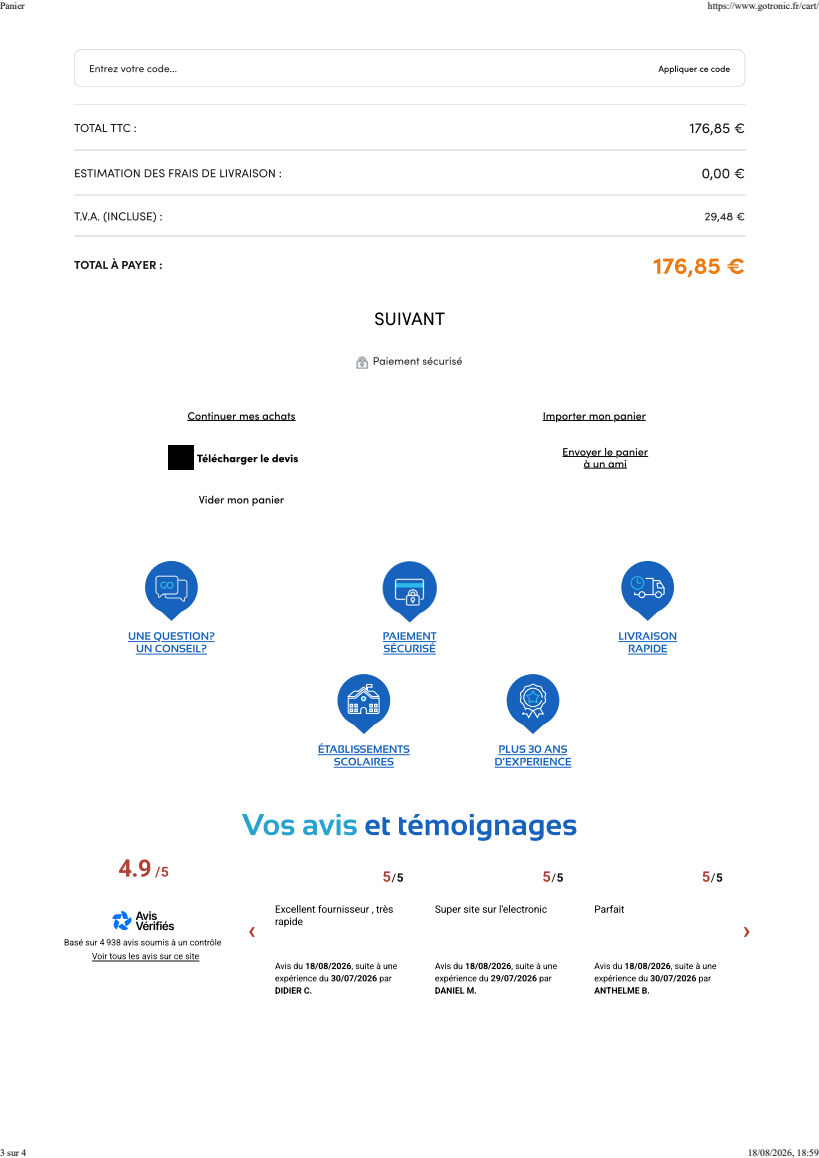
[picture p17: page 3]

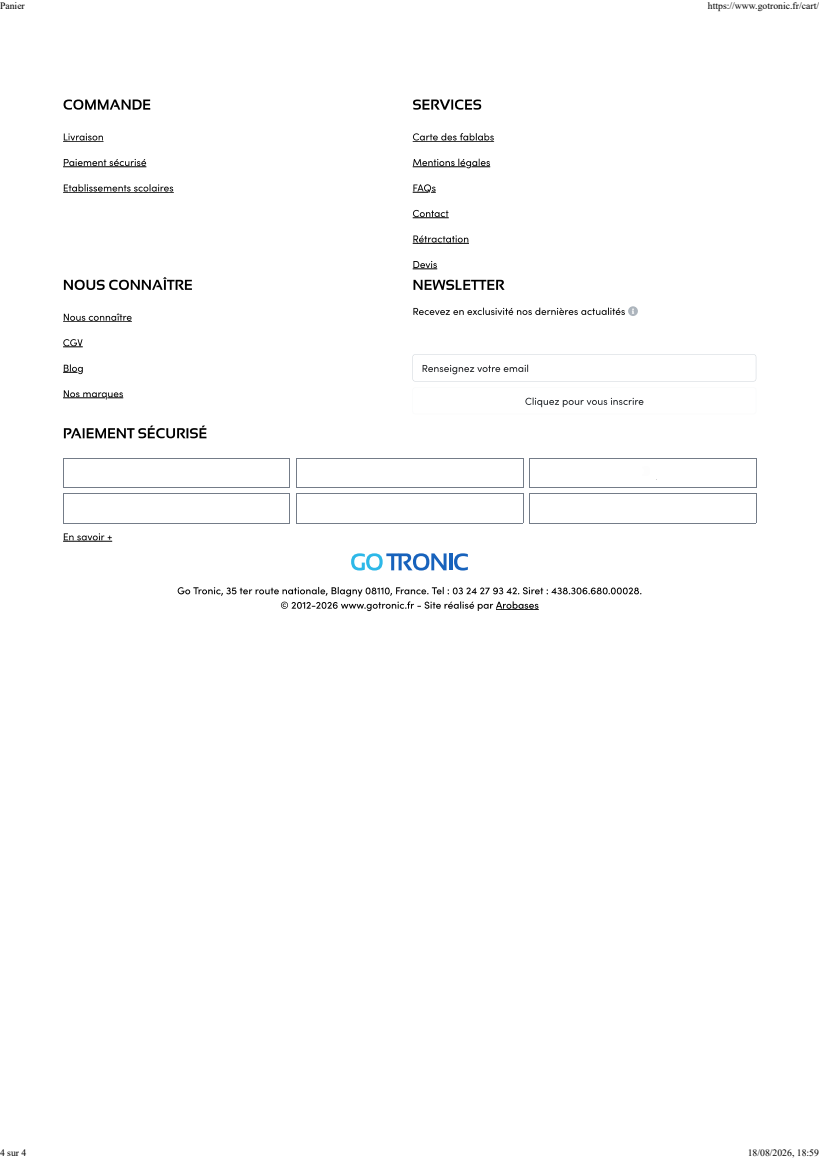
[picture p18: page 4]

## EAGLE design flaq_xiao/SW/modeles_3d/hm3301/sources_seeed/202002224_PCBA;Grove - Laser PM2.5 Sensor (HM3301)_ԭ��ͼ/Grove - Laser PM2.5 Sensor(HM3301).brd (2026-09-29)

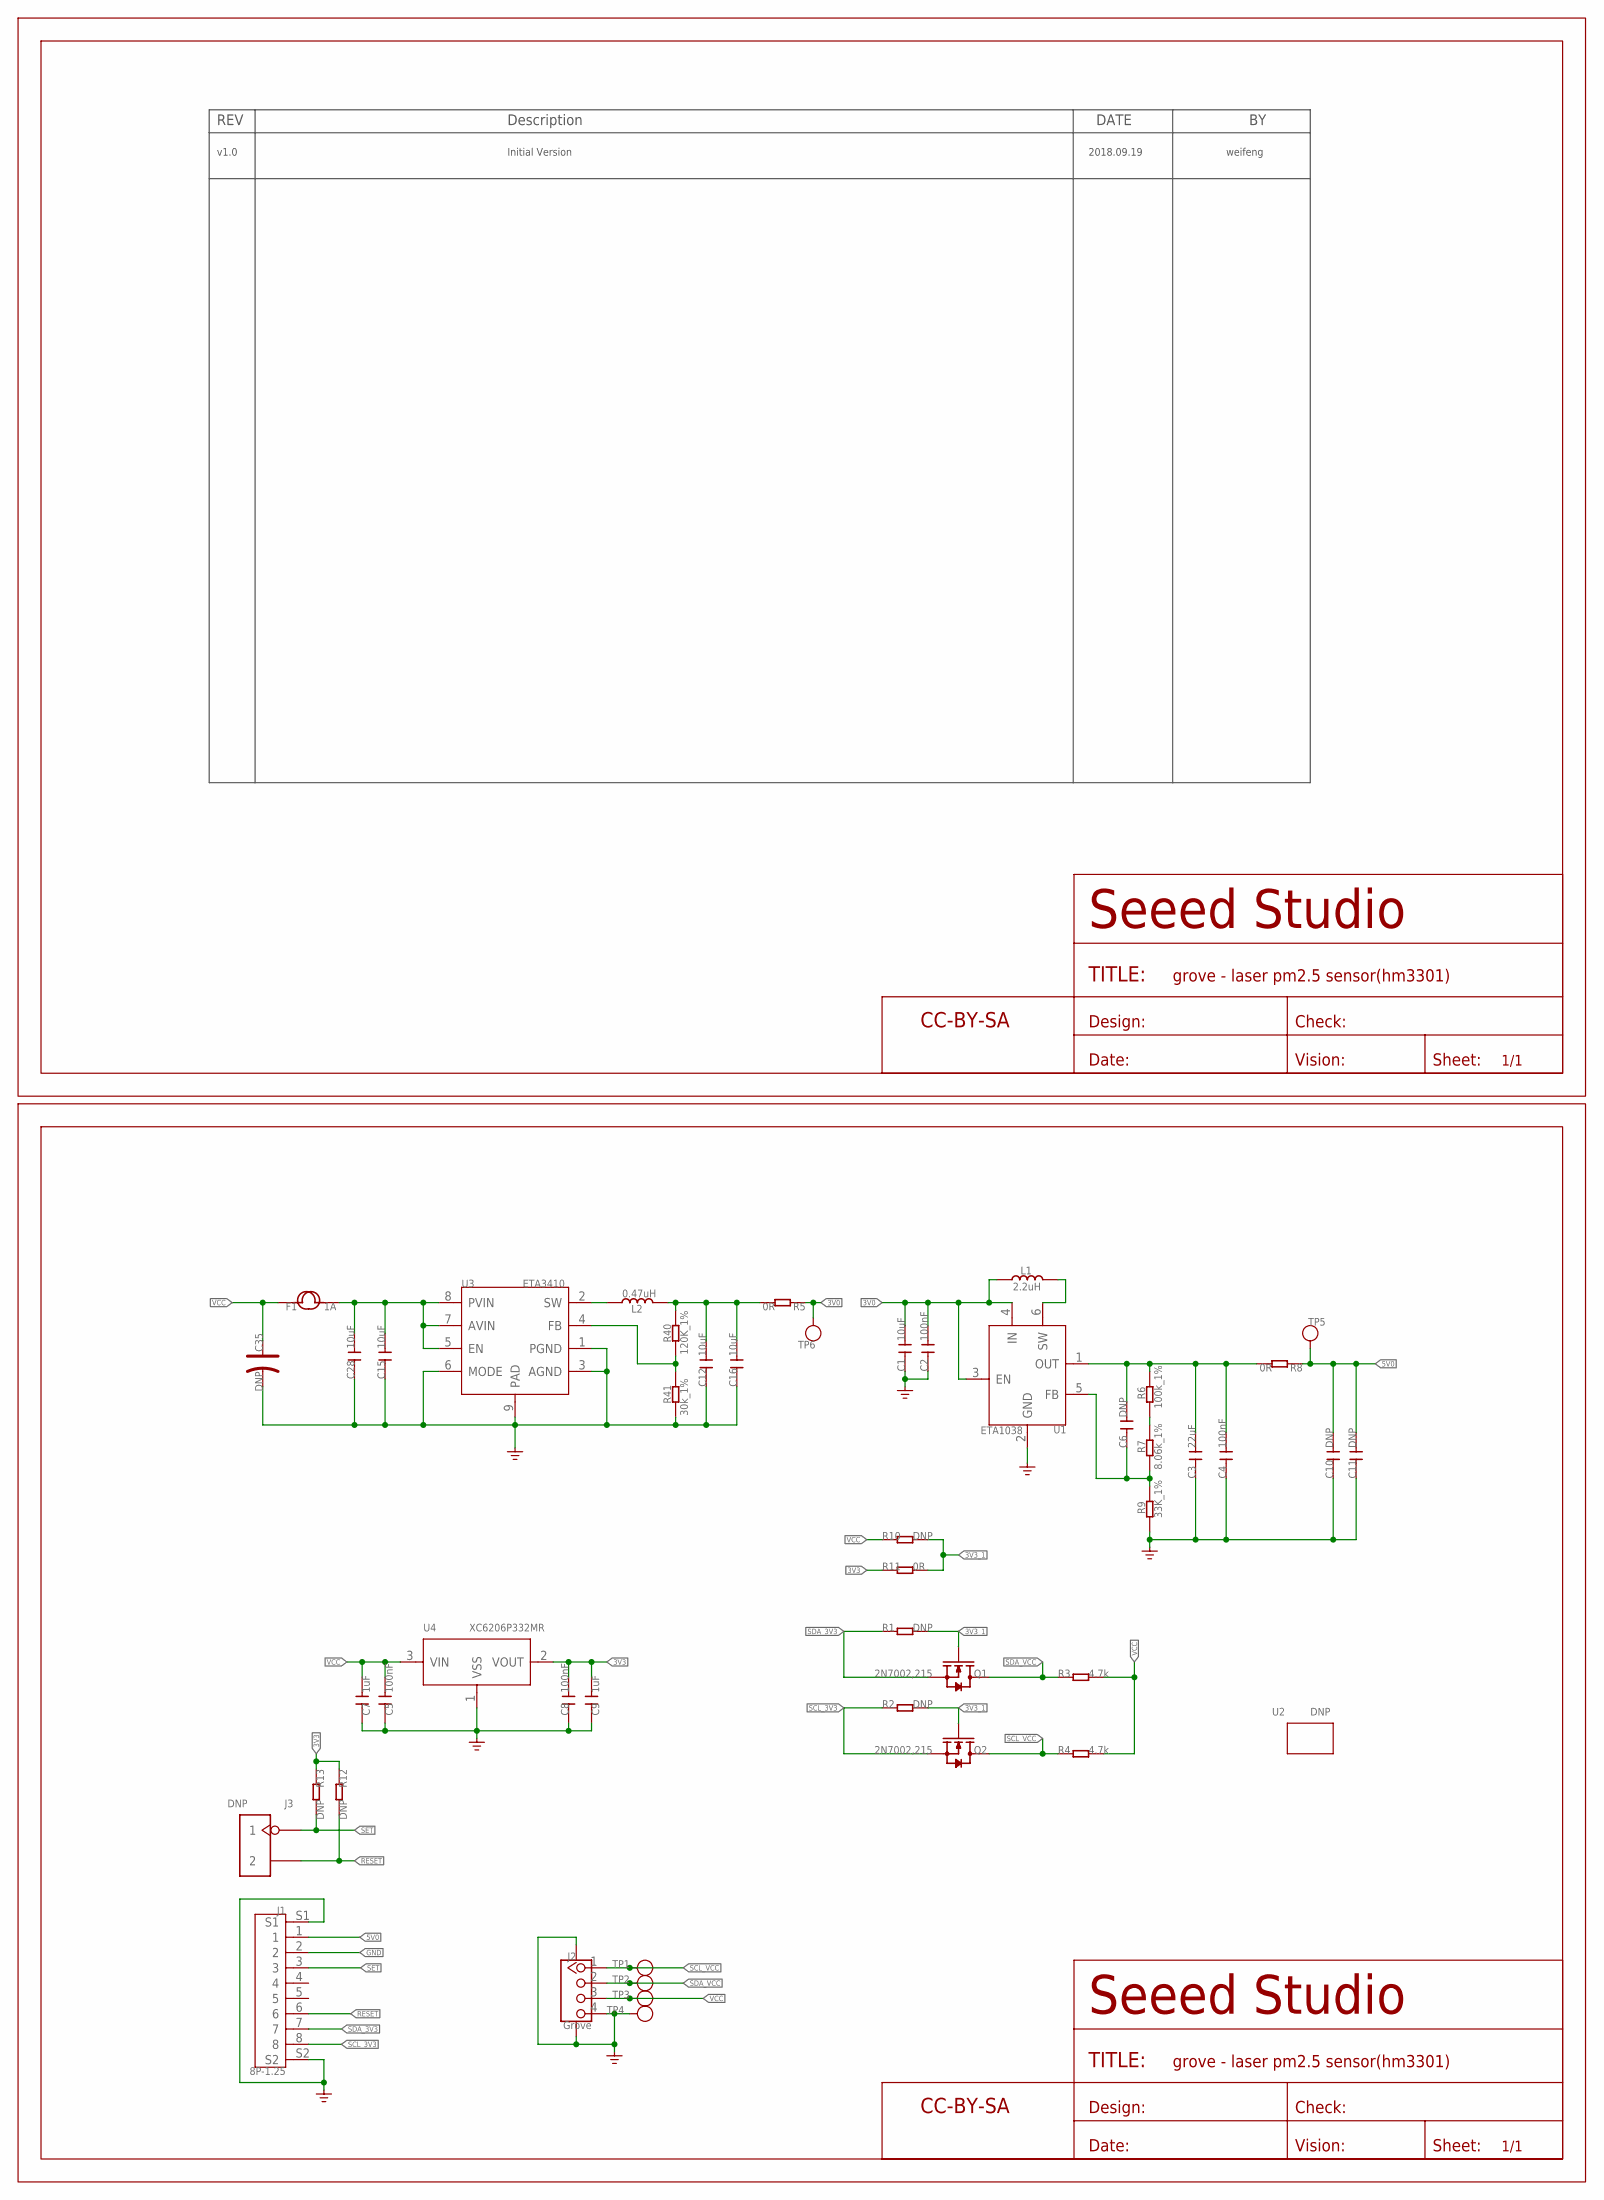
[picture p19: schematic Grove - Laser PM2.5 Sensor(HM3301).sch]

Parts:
C1, C12, C15, C16, C28: 10uF; C0603
C2, C4, C5, C8: 100nF; C0603
C3: 22uF; C0805
C6, C11: DNP; C0603
C7, C9: 1uF; C0603
C10: DNP; C0805
C35: DNP; AVX-B
F1: 1A; F0805
FR1: SEEEDSTUDIO-OPEN-SCH-FRAME; SEEEDSTUDIO-PCB-FRAME
J1: 8P-1.25; HEADER8+2P-SMD-1.25-15X3.5MM
J2: Grove; HW4-SMD-2.0-90D
J3: DNP; H2-2.54
L1: 2.2uH; L0806
L2: 0.47uH; L201610
Q1, Q2: 2N7002,215; SOT-23
R1, R2, R10, R12, R13: DNP; R0603
R3, R4: 4.7k; R0603
R5, R8, R11: 0R; R0603
R6: 100k_1%; R0603
R7: 8.06k_1%; R0603
R9: 33K_1%; R0603
R40: 120K_1%; R0603
R41: 30k_1%; R0603
TP1, TP2, TP3, TP4, TP5, TP6: TEST-POINT'4545'; TP-D45MIL
U1: ETA1038; SOT-23-6
U2: DNP; GROVE-80X40MM
U3: ETA3410; DFN8G-0.5-2X2MM
U4: XC6206P332MR; SOT-23
U$4: SEEEDSTUDIO-OPEN-SCH-FRAME; SEEEDSTUDIO-PCB-FRAME

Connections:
3V0: C1.2, C2.2, L1.1, R5.1, TP6.T, U1.3 (EN), U1.4 (IN)
3V3: C8.2, C9.2, R11.1, R12.1, R13.1, U4.2 (VOUT)
3V3_1: Q1.1 (G), Q2.1 (G), R1.2, R2.2, R10.2, R11.2
5V0: C10.2, C11.2, J1.1, R8.1, TP5.T
GND: C1.1, C2.1, C3.1, C4.1, C5.1, C7.1, C8.1, C9.1, C10.1, C11.1, C12.1, C15.1, C16.1, C28.1, C35.-, J1.2, J1.S1, J1.S2, J2.4, J2.SS1, J2.SS2, R9.2, R41.1, TP4.T, U1.2 (GND), U3.1 (PGND), U3.3 (AGND), U3.6 (MODE), U3.9 (PAD), U4.1 (VSS)
unnamed: C15.2, C28.2, F1.2, U3.5 (EN), U3.7 (AVIN), U3.8 (PVIN)
unnamed: L1.2, U1.6 (SW)
unnamed: C3.2, C4.2, C6.2, R6.1, R8.2, U1.1 (OUT)
unnamed: R6.2, R7.1
unnamed: C6.1, R7.2, R9.1, U1.5 (FB)
unnamed: R40.1, R41.2, U3.4 (FB)
unnamed: L2.1, U3.2 (SW)
unnamed: C12.2, C16.2, L2.2, R5.2, R40.2
RESET: J1.6, J3.2, R12.2
SCL_3V3: J1.8, Q2.2 (S), R2.1
SCL_VCC: J2.1, Q2.3 (D), R4.1, TP1.T
SDA_3V3: J1.7, Q1.2 (S), R1.1
SDA_VCC: J2.2, Q1.3 (D), R3.1, TP2.T
SET: J1.3, J3.1, R13.2
VCC: C5.2, C7.2, C35.+, F1.1, J2.3, R3.2, R4.2, R10.1, TP3.T, U4.3 (VIN)

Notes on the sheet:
v1.0
Initial Version
2018.09.19
weifeng

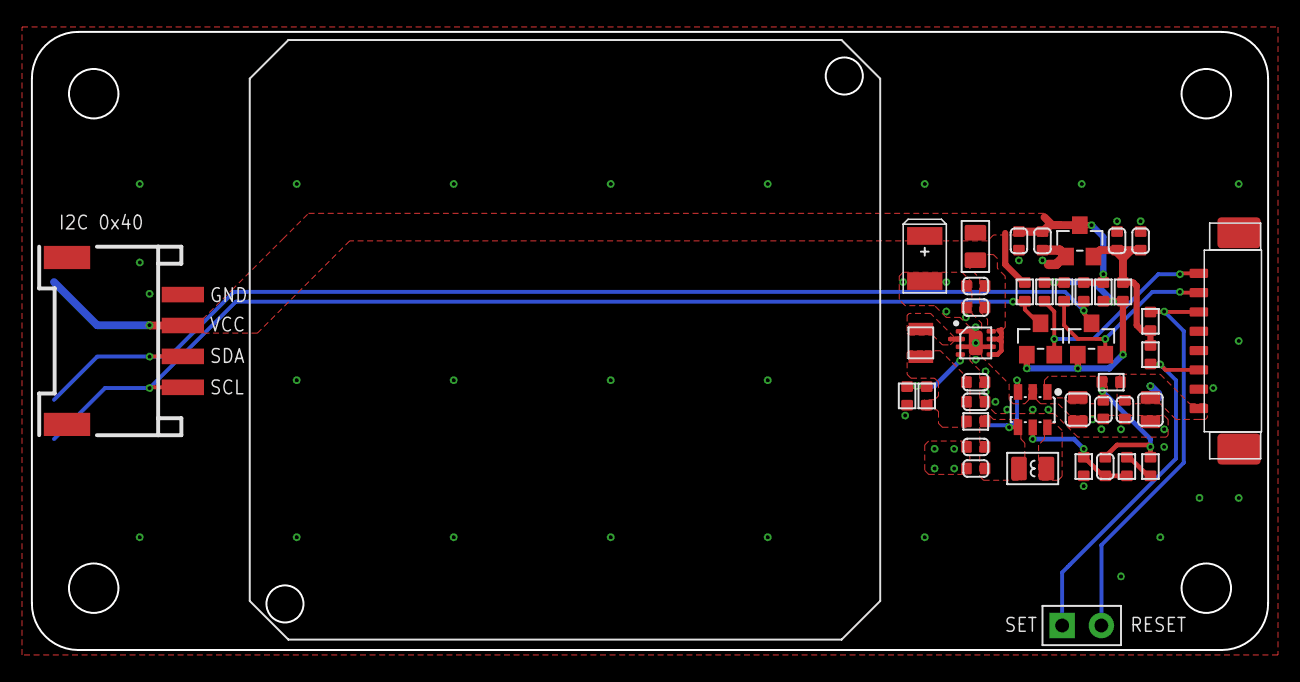
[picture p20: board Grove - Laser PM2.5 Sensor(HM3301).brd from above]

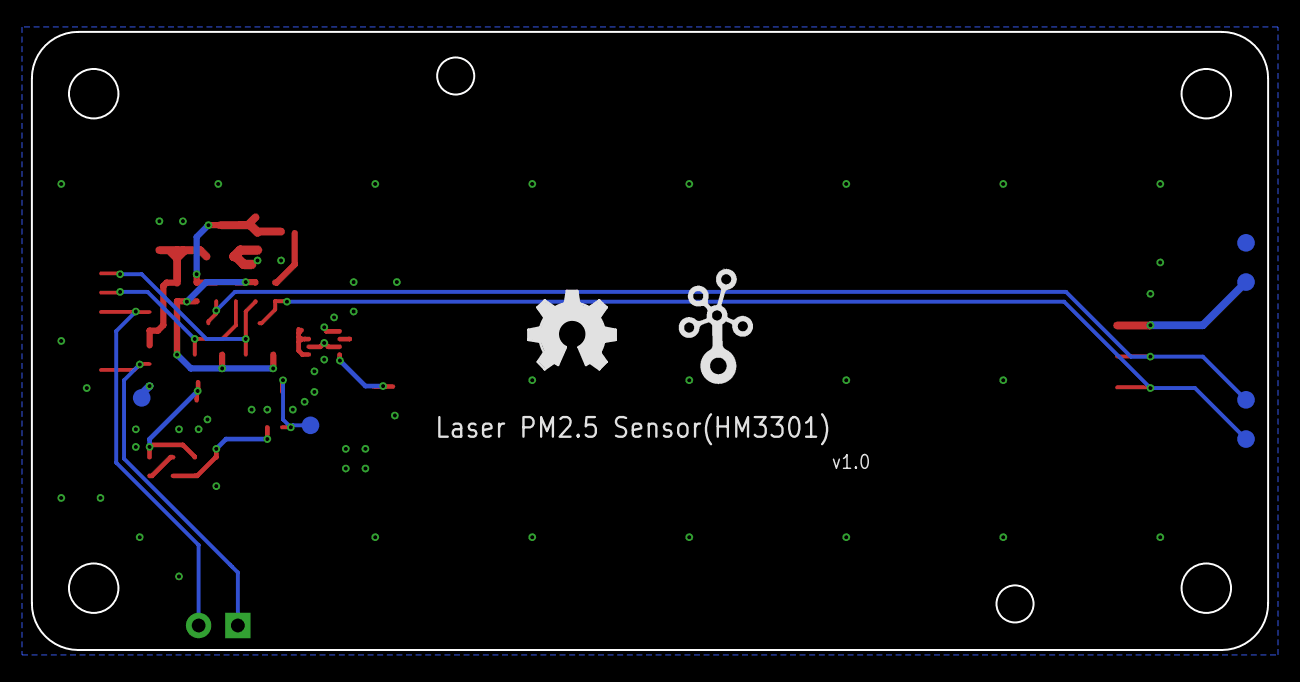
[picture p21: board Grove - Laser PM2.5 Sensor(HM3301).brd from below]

Board: 2 copper layers, 80.0 x 40.0 mm, 53 parts (8 on the bottom side), 20 nets.

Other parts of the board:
U$5: OSHW_FILLX200_NOTEXT
U$7: TWIGLOGO

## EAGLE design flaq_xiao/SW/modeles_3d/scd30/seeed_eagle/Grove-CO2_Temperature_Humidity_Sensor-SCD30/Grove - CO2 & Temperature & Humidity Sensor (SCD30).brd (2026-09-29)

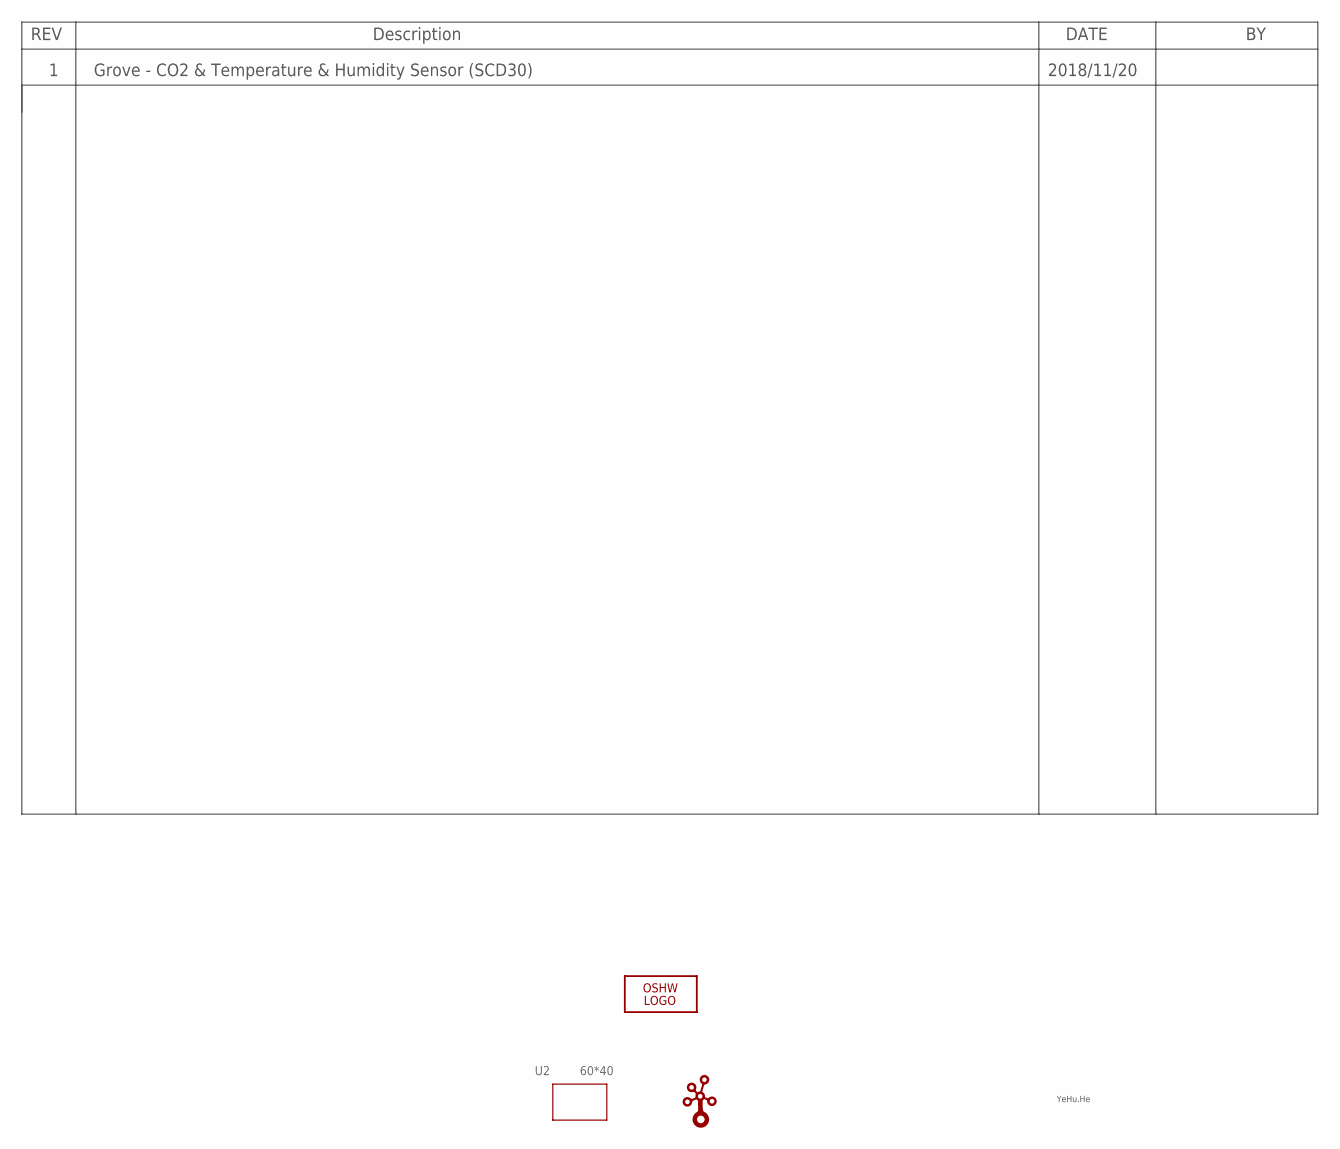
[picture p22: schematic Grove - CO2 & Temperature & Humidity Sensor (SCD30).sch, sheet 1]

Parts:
LOGO1: LOGO-OSHW-FILLX0200-NT; OSHW_FILLX200_NOTEXT
U2: 60*40; GROVE-60X40MM
U$4: LOGO-GROVE; GROVE-SILK-BIG

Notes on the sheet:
Grove - CO2 & Temperature & Humidity Sensor (SCD30)
2018/11/20
YeHu.He

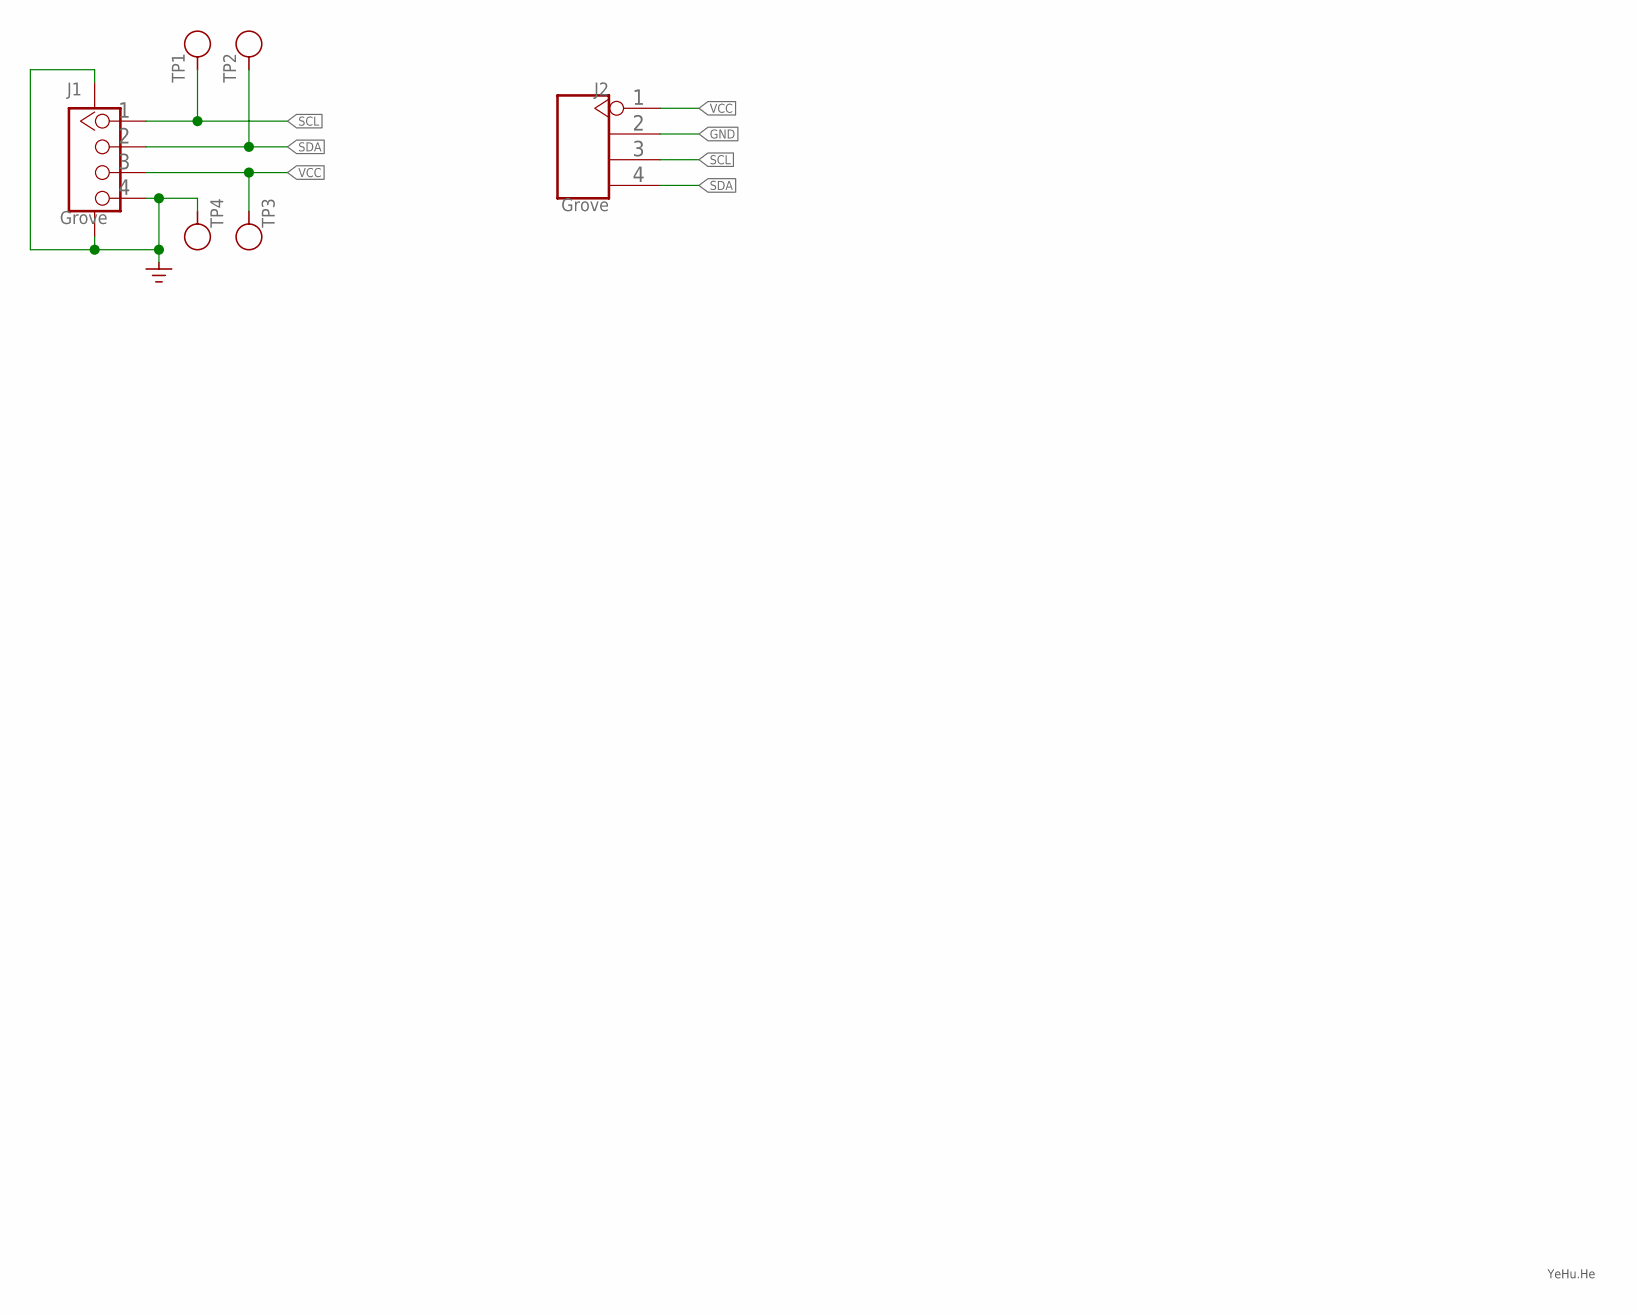
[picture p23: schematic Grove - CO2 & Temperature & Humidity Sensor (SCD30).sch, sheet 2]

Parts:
J1: Grove; HW4-SMD-2.0-90D
J2: Grove; H4-2.54
TP1, TP2, TP3, TP4: Test; TP-D45MIL

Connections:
GND: J1.4, J1.SS1, J1.SS2, J2.2, TP4.T
SCL: J1.1, J2.3, TP1.T
SDA: J1.2, J2.4, TP2.T
VCC: J1.3, J2.1, TP3.T

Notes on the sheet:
YeHu.He

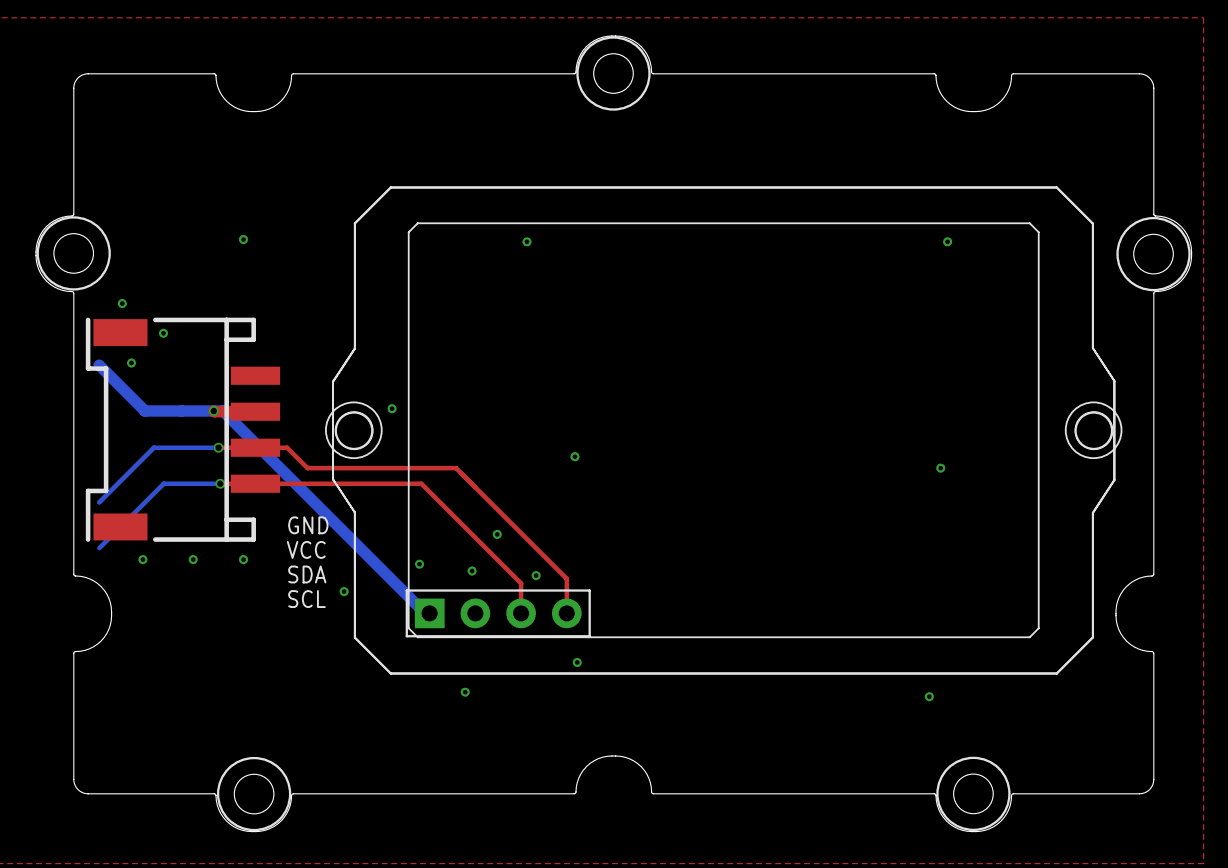
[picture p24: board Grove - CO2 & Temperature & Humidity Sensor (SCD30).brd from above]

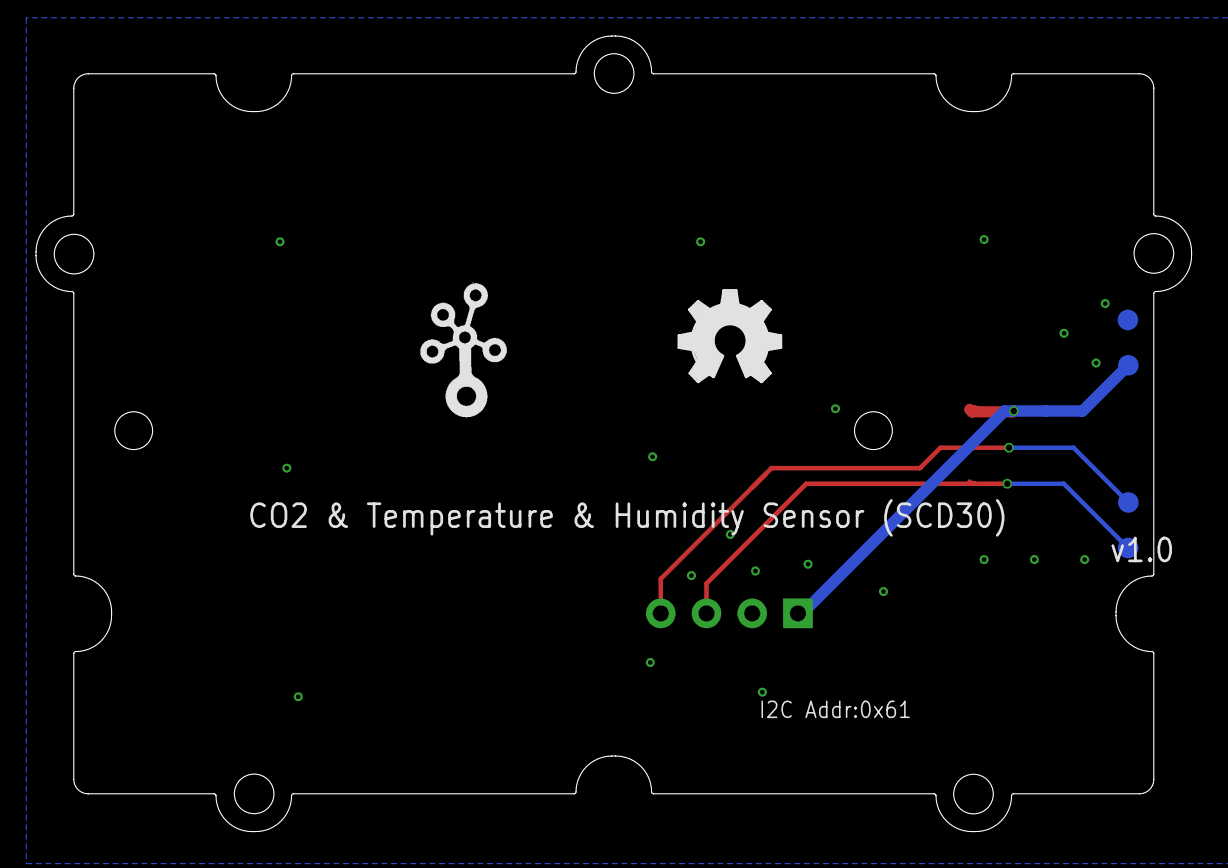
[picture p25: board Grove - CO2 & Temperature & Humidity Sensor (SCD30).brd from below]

Board: 2 copper layers, 64.2 x 44.2 mm, 9 parts (6 on the bottom side), 4 nets.

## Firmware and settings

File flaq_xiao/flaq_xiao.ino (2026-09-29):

#include <Arduino.h>
#include <Wire.h>
#include <SPI.h>
#include <SD.h>
#include <WiFi.h>
#include <WebServer.h>
#include <ESPmDNS.h>
#include <U8x8lib.h>
#include <Adafruit_SGP40.h>
#include <SparkFun_SCD30_Arduino_Library.h>
#include <DHT20.h>
#include <time.h>
#include <sys/time.h>
#include <math.h>
#include <esp_mac.h>

#include "dashboard.h"
#include "flaq_logo.h"
#if __has_include("config.h")
#include "config.h"
#else
#include "config.example.h"
#endif

static_assert(FLAQ_OLED_BUTTON_PIN != FLAQ_VENTILATION_BUTTON_PIN,
              "Les deux boutons du Grove Dual Button doivent utiliser deux broches distinctes");
#if FLAQ_WSP2110_ENABLED
static_assert(FLAQ_OLED_BUTTON_PIN != FLAQ_WSP2110_PIN,
              "Le bouton de page et le WSP2110 ne peuvent pas partager la meme broche");
static_assert(FLAQ_VENTILATION_BUTTON_PIN != FLAQ_WSP2110_PIN,
              "Le bouton de ventilation et le WSP2110 ne peuvent pas partager la meme broche");
#endif

// -----------------------------------------------------------------------------
// FLAQ XIAO ESP32S3 — station académique de qualité de l'air des FabLabs
// -----------------------------------------------------------------------------

constexpr uint8_t RTC_ADDRESS = 0x51;
constexpr uint8_t HM3301_ADDRESS = 0x40;
constexpr size_t HISTORY_CAPACITY = 8640;  // 24 h à une mesure toutes les 10 s
constexpr size_t EVENT_CAPACITY = 200;
constexpr uint16_t SOS_DURATIONS_MS[] = {
    150, 150, 150, 150, 150, 450,
    450, 150, 450, 150, 450, 450,
    150, 150, 150, 150, 150
};
constexpr uint8_t REQUIRED_SENSOR_TOTAL = 4;

U8X8_SSD1306_128X64_NONAME_HW_I2C oled(U8X8_PIN_NONE);
Adafruit_SGP40 sgp40;
SCD30 scd30;
DHT20 dht20;
WebServer server(80);
SPIClass sdSpi(FSPI);

struct Measurement {
    uint32_t timestamp;
    float co2;
    float voc;
    float hcho;
    float pm1;
    float pm25;
    float pm10;
    float temperature;
    float humidity;
    uint8_t quality;
    bool ventilation;
};

struct EventRecord {
    uint32_t start;
    uint32_t end;
    uint32_t peakAt;
    char parameter[14];
    char unit[12];
    float threshold;
    float average;
    float maximum;
};

struct EventTracker {
    bool active = false;
    uint8_t aboveCount = 0;
    uint8_t belowCount = 0;
    uint32_t pendingStart = 0;
    uint32_t start = 0;
    uint32_t peakAt = 0;
    float pendingSum = 0;
    float pendingMax = -INFINITY;
    float sum = 0;
    float maximum = -INFINITY;
    uint32_t samples = 0;
};

struct EventRule {
    const char* parameter;
    const char* unit;
    float threshold;
    float reset;
};

struct WifiNetwork {
    const char* ssid;
    const char* password;
};

#ifdef FLAQ_WIFI_NETWORKS
const WifiNetwork WIFI_NETWORKS[] = {FLAQ_WIFI_NETWORKS};
#else
const WifiNetwork WIFI_NETWORKS[] = {{FLAQ_WIFI_SSID, FLAQ_WIFI_PASSWORD}};
#endif
constexpr size_t WIFI_NETWORK_COUNT = sizeof(WIFI_NETWORKS) / sizeof(WIFI_NETWORKS[0]);

enum EventId : uint8_t {
    EVENT_CO2,
    EVENT_VOC,
    EVENT_HCHO,
    EVENT_PM25,
    EVENT_PM25_24H,
    EVENT_PM10,
    EVENT_RULE_COUNT
};

const EventRule EVENT_RULES[EVENT_RULE_COUNT] = {
    {"CO2", "ppm", FLAQ_CO2_RED_PPM, FLAQ_CO2_RESET_PPM},
    {"VOC", "index", FLAQ_VOC_RED_INDEX, FLAQ_VOC_RESET_INDEX},
    {"HCHO estime", "ppm", FLAQ_HCHO_RED_PPM, FLAQ_HCHO_RESET_PPM},
    {"PM2.5", "ug/m3", FLAQ_PM25_RED_UGM3, FLAQ_PM25_RESET_UGM3},
    {"PM2.5 24h", "ug/m3", FLAQ_PM25_24H_LIMIT_UGM3, FLAQ_PM25_24H_RESET_UGM3},
    {"PM10", "ug/m3", FLAQ_PM10_RED_UGM3, FLAQ_PM10_RESET_UGM3},
};

Measurement currentMeasurement = {0, NAN, NAN, NAN, NAN, NAN, NAN, NAN, NAN, 0, false};
Measurement* historyBuffer = nullptr;
size_t historyHead = 0;
size_t historyCount = 0;
double pm25Sum = 0;
uint32_t pm25ValidCount = 0;

EventRecord* eventBuffer = nullptr;
size_t eventHead = 0;
size_t eventCount = 0;
EventTracker eventTrackers[EVENT_RULE_COUNT];

bool rtcOk = false;
bool i2cMuxOk = false;
bool sdOk = false;
bool scdOk = false;
bool hmOk = false;
bool sgpOk = false;
bool wspOk = false;
uint8_t wspValidReadings = 0;
bool dhtOk = false;
bool apMode = false;
bool alarmActive = false;
uint8_t globalRedCount = 0;
const char* qualityCause = "Aucun";

File measurementFile;
String measurementPath;
uint32_t lastMeasurementFlush = 0;
uint8_t hmBuffer[29];
uint8_t hmConsecutiveFailures = 0;
size_t hmLastReceivedBytes = 0;
bool hmHasValidFrame = false;
float wspRsRatio = NAN;
float wspAdcVoltage = NAN;
uint8_t oledPage = 0;
bool oledAwake = true;
bool buttonStableState = false;
bool buttonLastReading = false;
bool ventilationActive = false;
bool ventilationButtonStableState = false;
bool ventilationButtonLastReading = false;
bool soundMuted = false;
bool buttonChordActive = false;
uint32_t lastSample = 0;
uint32_t lastSgp40 = 0;
uint32_t lastButtonChange = 0;
uint32_t lastVentilationButtonChange = 0;
uint32_t lastOledActivity = 0;
uint32_t lastWifiAttempt = 0;
uint32_t lastRtcNtpWrite = 0;
uint32_t buzzerStepStarted = 0;
uint8_t buzzerStep = 0;
bool buzzerTriggeredForAlarm = false;
size_t selectedWifiNetwork = 0;

// -----------------------------------------------------------------------------
// Utilitaires
// -----------------------------------------------------------------------------

bool initializeI2cMultiplexer() {
#if FLAQ_I2C_MUX_ENABLED
    Wire.beginTransmission(FLAQ_I2C_MUX_ADDRESS);
    Wire.write(FLAQ_I2C_MUX_CHANNEL_MASK);
    bool ok = Wire.endTransmission() == 0;
    Serial.printf("Hub I2C TCA9548A 0x%02X: %s (canaux 0x%02X)\n",
                  FLAQ_I2C_MUX_ADDRESS, ok ? "OK" : "ERREUR",
                  FLAQ_I2C_MUX_CHANNEL_MASK);
    return ok;
#else
    Serial.println("Multiplexeur I2C desactive");
    return true;
#endif
}

uint8_t bcdToDec(uint8_t value) {
    return (value / 16 * 10) + (value % 16);
}

uint8_t decToBcd(uint8_t value) {
    return (value / 10 * 16) + (value % 10);
}

String jsonNumber(float value, uint8_t decimals = 1) {
    return isfinite(value) ? String(value, static_cast<unsigned int>(decimals)) : String("null");
}

String localIso(uint32_t epoch) {
    if (epoch < 946684800UL) return String("heure inconnue");
    time_t raw = static_cast<time_t>(epoch);
    struct tm tmValue;
    localtime_r(&raw, &tmValue);
    char buffer[24];
    strftime(buffer, sizeof(buffer), "%Y-%m-%d %H:%M:%S", &tmValue);
    return String(buffer);
}

String dayPath(uint32_t epoch) {
    time_t raw = static_cast<time_t>(epoch);
    struct tm tmValue;
    localtime_r(&raw, &tmValue);
    char buffer[28];
    strftime(buffer, sizeof(buffer), "/data/%Y%m%d.csv", &tmValue);
    return String(buffer);
}

uint32_t nowEpoch() {
    time_t value = time(nullptr);
    return value > 0 ? static_cast<uint32_t>(value) : 0;
}

// -----------------------------------------------------------------------------
// RTC Grove PCF85063
// -----------------------------------------------------------------------------

bool readRtc(struct tm& value) {
    Wire.beginTransmission(RTC_ADDRESS);
    Wire.write(0x04);
    if (Wire.endTransmission(false) != 0) return false;
    if (Wire.requestFrom(RTC_ADDRESS, static_cast<uint8_t>(7)) != 7) return false;

    uint8_t secondsRaw = Wire.read();
    value = {};
    value.tm_sec = bcdToDec(secondsRaw & 0x7F);
    value.tm_min = bcdToDec(Wire.read() & 0x7F);
    value.tm_hour = bcdToDec(Wire.read() & 0x3F);
    value.tm_mday = bcdToDec(Wire.read() & 0x3F);
    value.tm_wday = bcdToDec(Wire.read() & 0x07);
    value.tm_mon = bcdToDec(Wire.read() & 0x1F) - 1;
    value.tm_year = bcdToDec(Wire.read()) + 100;
    value.tm_isdst = -1;

    bool validFields = value.tm_year >= 120 && value.tm_year <= 199 &&
                       value.tm_mon >= 0 && value.tm_mon <= 11 &&
                       value.tm_mday >= 1 && value.tm_mday <= 31 &&
                       value.tm_hour <= 23 && value.tm_min <= 59 && value.tm_sec <= 59;
    return !(secondsRaw & 0x80) && validFields;
}

bool writeRtc(time_t epoch) {
    struct tm localValue;
    localtime_r(&epoch, &localValue);

    Wire.beginTransmission(RTC_ADDRESS);
    Wire.write(0x00);
    Wire.write(0x00);
    Wire.write(0x00);
    if (Wire.endTransmission() != 0) return false;

    Wire.beginTransmission(RTC_ADDRESS);
    Wire.write(0x04);
    Wire.write(decToBcd(localValue.tm_sec));
    Wire.write(decToBcd(localValue.tm_min));
    Wire.write(decToBcd(localValue.tm_hour));
    Wire.write(decToBcd(localValue.tm_mday));
    Wire.write(decToBcd(localValue.tm_wday));
    Wire.write(decToBcd(localValue.tm_mon + 1));
    Wire.write(decToBcd((localValue.tm_year + 1900) - 2000));
    return Wire.endTransmission() == 0;
}

void initializeClockFromRtc() {
    setenv("TZ", FLAQ_TIMEZONE, 1);
    tzset();
    struct tm rtcTime;
    rtcOk = readRtc(rtcTime);
    if (!rtcOk) {
        Serial.println("RTC PCF85063 absente ou heure invalide");
        return;
    }
    time_t epoch = mktime(&rtcTime);
    timeval tv = {epoch, 0};
    settimeofday(&tv, nullptr);
    Serial.printf("Heure RTC chargee: %s\n", localIso(epoch).c_str());
}

void synchronizeNtp() {
    if (WiFi.status() != WL_CONNECTED || apMode) return;
    configTzTime(FLAQ_TIMEZONE, FLAQ_NTP_SERVER_1, FLAQ_NTP_SERVER_2);
    struct tm networkTime;
    if (getLocalTime(&networkTime, 5000)) {
        time_t epoch = time(nullptr);
        rtcOk = writeRtc(epoch);
        lastRtcNtpWrite = millis();
        Serial.printf("RTC corrigee par NTP: %s\n", localIso(epoch).c_str());
    } else {
        Serial.println("NTP indisponible, conservation de l'heure RTC");
    }
}

// -----------------------------------------------------------------------------
// Historique en PSRAM
// -----------------------------------------------------------------------------

Measurement& historyAt(size_t logicalIndex) {
    size_t first = (historyHead + HISTORY_CAPACITY - historyCount) % HISTORY_CAPACITY;
    return historyBuffer[(first + logicalIndex) % HISTORY_CAPACITY];
}

void removeOldestHistory() {
    if (!historyCount) return;
    Measurement& oldest = historyAt(0);
    if (isfinite(oldest.pm25)) {
        pm25Sum -= oldest.pm25;
        if (pm25ValidCount) pm25ValidCount--;
    }
    historyCount--;
}

void appendHistory(const Measurement& measurement) {
    if (!historyBuffer) return;
    uint32_t cutoff = measurement.timestamp > 86400UL ? measurement.timestamp - 86400UL : 0;
    while (historyCount && historyAt(0).timestamp < cutoff) removeOldestHistory();
    if (historyCount == HISTORY_CAPACITY) removeOldestHistory();

    historyBuffer[historyHead] = measurement;
    historyHead = (historyHead + 1) % HISTORY_CAPACITY;
    historyCount++;
    if (isfinite(measurement.pm25)) {
        pm25Sum += measurement.pm25;
        pm25ValidCount++;
    }
}

float pm25Average24h() {
    return pm25ValidCount ? static_cast<float>(pm25Sum / pm25ValidCount) : NAN;
}

uint32_t historyCoverageSeconds() {
    if (historyCount < 2) return 0;
    return historyAt(historyCount - 1).timestamp - historyAt(0).timestamp;
}

bool pm25AverageReady() {
    return historyCoverageSeconds() >= 23UL * 3600UL;
}

// -----------------------------------------------------------------------------
// Stockage microSD
// -----------------------------------------------------------------------------

bool parseMeasurementLine(const char* line, Measurement& m) {
    unsigned long timestamp = 0;
    int quality = 0;
    int ventilation = 0;
    int fields = sscanf(line, "%lu,%f,%f,%f,%f,%f,%f,%f,%f,%d,%d",
                        &timestamp, &m.co2, &m.voc, &m.hcho, &m.pm1, &m.pm25,
                        &m.pm10, &m.temperature, &m.humidity, &quality, &ventilation);
    m.timestamp = static_cast<uint32_t>(timestamp);
    m.quality = static_cast<uint8_t>(quality);
    m.ventilation = fields >= 11 && ventilation != 0;
    return (fields == 10 || fields == 11) && m.timestamp > 946684800UL;
}

void loadHistoryFile(const String& path, uint32_t cutoff) {
    File file = SD.open(path, FILE_READ);
    if (!file) return;
    char line[220];
    while (file.available()) {
        size_t count = file.readBytesUntil('\n', line, sizeof(line) - 1);
        line[count] = '\0';
        if (line[0] < '0' || line[0] > '9') continue;
        Measurement m;
        if (parseMeasurementLine(line, m) && m.timestamp >= cutoff) appendHistory(m);
        delay(0);
    }
    file.close();
}

void loadRecentHistory() {
    uint32_t now = nowEpoch();
    if (!sdOk || now < 946684800UL) return;
    uint32_t cutoff = now - 86400UL;
    String yesterday = dayPath(cutoff);
    String today = dayPath(now);
    loadHistoryFile(yesterday, cutoff);
    if (today != yesterday) loadHistoryFile(today, cutoff);
    Serial.printf("Historique restaure: %u mesures\n", static_cast<unsigned>(historyCount));
}

void ensureMeasurementFile(uint32_t timestamp) {
    if (!sdOk) return;
    String wantedPath = dayPath(timestamp);
    if (measurementFile && wantedPath == measurementPath) return;
    if (measurementFile) {
        measurementFile.flush();
        measurementFile.close();
    }
    bool isNew = !SD.exists(wantedPath);
    measurementFile = SD.open(wantedPath, FILE_APPEND);
    measurementPath = wantedPath;
    if (measurementFile && isNew) {
        measurementFile.println("epoch,co2_ppm,voc_index,hcho_estime_ppm,pm1_ugm3,pm25_ugm3,pm10_ugm3,temperature_c,humidity_pct,quality,ventilation");
        measurementFile.flush();
    }
}

void logMeasurement(const Measurement& m) {
    if (!sdOk || m.timestamp < 946684800UL) return;
    ensureMeasurementFile(m.timestamp);
    if (!measurementFile) {
        sdOk = false;
        return;
    }
    measurementFile.printf("%lu,%.1f,%.0f,%.1f,%.1f,%.1f,%.1f,%.2f,%.2f,%u,%u\n",
                           static_cast<unsigned long>(m.timestamp), m.co2, m.voc,
                           m.hcho, m.pm1, m.pm25, m.pm10, m.temperature,
                           m.humidity, m.quality, static_cast<unsigned>(m.ventilation));
    if (millis() - lastMeasurementFlush >= FLAQ_SD_FLUSH_INTERVAL_MS) {
        measurementFile.flush();
        lastMeasurementFlush = millis();
    }
}

void appendEventMemory(const EventRecord& event) {
    if (!eventBuffer) return;
    eventBuffer[eventHead] = event;
    eventHead = (eventHead + 1) % EVENT_CAPACITY;
    if (eventCount < EVENT_CAPACITY) eventCount++;
}

EventRecord& eventAt(size_t logicalIndex) {
    size_t first = (eventHead + EVENT_CAPACITY - eventCount) % EVENT_CAPACITY;
    return eventBuffer[(first + logicalIndex) % EVENT_CAPACITY];
}

void persistEvent(const EventRecord& event) {
    appendEventMemory(event);
    if (!sdOk) return;
    bool isNew = !SD.exists("/events.csv");
    File file = SD.open("/events.csv", FILE_APPEND);
    if (!file) return;
    if (isNew) file.println("start_epoch,end_epoch,parameter,unit,threshold,average,maximum,peak_epoch");
    file.printf("%lu,%lu,%s,%s,%.2f,%.2f,%.2f,%lu\n",
                static_cast<unsigned long>(event.start),
                static_cast<unsigned long>(event.end), event.parameter, event.unit,
                event.threshold, event.average, event.maximum,
                static_cast<unsigned long>(event.peakAt));
    file.flush();
    file.close();
}

void loadEvents() {
    if (!sdOk || !SD.exists("/events.csv")) return;
    File file = SD.open("/events.csv", FILE_READ);
    char line[180];
    while (file.available()) {
        size_t length = file.readBytesUntil('\n', line, sizeof(line) - 1);
        line[length] = '\0';
        if (line[0] < '0' || line[0] > '9') continue;
        EventRecord event = {};
        unsigned long start, end, peak;
        int fields = sscanf(line, "%lu,%lu,%13[^,],%11[^,],%f,%f,%f,%lu",
                            &start, &end, event.parameter, event.unit,
                            &event.threshold, &event.average, &event.maximum, &peak);
        if (fields == 8) {
            event.start = start;
            event.end = end;
            event.peakAt = peak;
            appendEventMemory(event);
        }
    }
    file.close();
}

void initializeStorage() {
    sdSpi.begin(FLAQ_SD_SCK_PIN, FLAQ_SD_MISO_PIN, FLAQ_SD_MOSI_PIN, FLAQ_SD_CS_PIN);
    sdOk = SD.begin(FLAQ_SD_CS_PIN, sdSpi, 10000000);
    if (!sdOk) {
        Serial.println("microSD indisponible: fonctionnement temporaire en PSRAM");
        return;
    }
    if (!SD.exists("/data")) SD.mkdir("/data");
    loadRecentHistory();
    loadEvents();
}

// -----------------------------------------------------------------------------
// Qualité de l'air et événements
// -----------------------------------------------------------------------------

uint8_t pollutantLevel(float value, float yellow, float orange, float red) {
    if (!isfinite(value)) return 0;
    if (value >= red) return 3;
    if (value >= orange) return 2;
    if (value >= yellow) return 1;
    return 0;
}

uint8_t computeQuality() {
    uint8_t best = 0;
    qualityCause = "Aucun";
    struct Candidate { uint8_t level; const char* name; } candidates[] = {
        {pollutantLevel(currentMeasurement.co2, FLAQ_CO2_YELLOW_PPM, FLAQ_CO2_ORANGE_PPM, FLAQ_CO2_RED_PPM), "CO2"},
        {pollutantLevel(currentMeasurement.voc, FLAQ_VOC_YELLOW_INDEX, FLAQ_VOC_ORANGE_INDEX, FLAQ_VOC_RED_INDEX), "VOC"},
#if FLAQ_WSP2110_ENABLED
        {pollutantLevel(currentMeasurement.hcho, FLAQ_HCHO_YELLOW_PPM, FLAQ_HCHO_ORANGE_PPM, FLAQ_HCHO_RED_PPM), "HCHO estime"},
#endif
        {pollutantLevel(currentMeasurement.pm25, FLAQ_PM25_YELLOW_UGM3, FLAQ_PM25_ORANGE_UGM3, FLAQ_PM25_RED_UGM3), "PM2.5"},
        {pollutantLevel(currentMeasurement.pm10, FLAQ_PM10_YELLOW_UGM3, FLAQ_PM10_ORANGE_UGM3, FLAQ_PM10_RED_UGM3), "PM10"},
    };
    for (const Candidate& candidate : candidates) {
        if (candidate.level > best) {
            best = candidate.level;
            qualityCause = candidate.name;
        }
    }
    return best;
}

void closeEvent(EventId id, uint32_t endTime) {
    EventTracker& tracker = eventTrackers[id];
    const EventRule& rule = EVENT_RULES[id];
    if (!tracker.active) return;
    EventRecord event = {};
    event.start = tracker.start;
    event.end = max(endTime, tracker.start);
    event.peakAt = tracker.peakAt;
    strlcpy(event.parameter, rule.parameter, sizeof(event.parameter));
    strlcpy(event.unit, rule.unit, sizeof(event.unit));
    event.threshold = rule.threshold;
    event.average = tracker.samples ? tracker.sum / tracker.samples : tracker.maximum;
    event.maximum = tracker.maximum;
    persistEvent(event);
    tracker = EventTracker();
}

void updateEvent(EventId id, float value, uint32_t timestamp, bool enabled = true) {
    EventTracker& tracker = eventTrackers[id];
    const EventRule& rule = EVENT_RULES[id];
    if (!enabled || !isfinite(value)) return;

    if (!tracker.active) {
        if (value >= rule.threshold) {
            if (tracker.aboveCount == 0) {
                tracker.pendingStart = timestamp;
                tracker.pendingSum = 0;
                tracker.pendingMax = value;
            }
            tracker.aboveCount++;
            tracker.pendingSum += value;
            tracker.pendingMax = max(tracker.pendingMax, value);
            if (tracker.aboveCount >= FLAQ_CONFIRMATION_SAMPLES) {
                tracker.active = true;
                tracker.start = tracker.pendingStart;
                tracker.sum = tracker.pendingSum;
                tracker.samples = tracker.aboveCount;
                tracker.maximum = tracker.pendingMax;
                tracker.peakAt = timestamp;
                tracker.belowCount = 0;
            }
        } else {
            tracker.aboveCount = 0;
            tracker.pendingSum = 0;
            tracker.pendingMax = -INFINITY;
        }
        return;
    }

    if (value < rule.reset) {
        tracker.belowCount++;
        if (tracker.belowCount >= FLAQ_CONFIRMATION_SAMPLES) {
            uint32_t endTime = timestamp - (FLAQ_CONFIRMATION_SAMPLES - 1) * (FLAQ_SAMPLE_INTERVAL_MS / 1000UL);
            closeEvent(id, endTime);
        }
    } else {
        tracker.belowCount = 0;
        tracker.sum += value;
        tracker.samples++;
        if (value > tracker.maximum) {
            tracker.maximum = value;
            tracker.peakAt = timestamp;
        }
    }
}

void updateAllEvents(uint32_t timestamp) {
    updateEvent(EVENT_CO2, currentMeasurement.co2, timestamp, scdOk);
    updateEvent(EVENT_VOC, currentMeasurement.voc, timestamp, sgpOk);
#if FLAQ_WSP2110_ENABLED
    updateEvent(EVENT_HCHO, currentMeasurement.hcho, timestamp, wspOk);
#endif
    updateEvent(EVENT_PM25, currentMeasurement.pm25, timestamp, hmOk);
    updateEvent(EVENT_PM25_24H, pm25Average24h(), timestamp, pm25AverageReady());
    updateEvent(EVENT_PM10, currentMeasurement.pm10, timestamp, hmOk);
}

void updateAlarm() {
    if (currentMeasurement.quality == 3) {
        if (globalRedCount < FLAQ_CONFIRMATION_SAMPLES) globalRedCount++;
    } else if (currentMeasurement.quality <= 2) {
        globalRedCount = 0;
    }
    alarmActive = globalRedCount >= FLAQ_CONFIRMATION_SAMPLES;
}
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
void loop() {
    uint32_t now = millis();
    serviceNetwork();
    serviceBuzzer();

    if (now - lastSgp40 >= FLAQ_SGP40_INTERVAL_MS) {
        lastSgp40 = now;
        readSgp40();
    }
    if (now - lastSample >= FLAQ_SAMPLE_INTERVAL_MS) {
        lastSample = now;
        takeSample();
        if (oledAwake) drawOled();
    }
    serviceButtons(now);
    delay(2);
}

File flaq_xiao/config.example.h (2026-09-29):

#pragma once

// Copiez ce fichier sous le nom config.h pour personnaliser la station.
// Si config.h est absent, le firmware utilise ces valeurs et crée le point
// d'accès Wi-Fi local FLAQ-XIAO.

#define FLAQ_WIFI_SSID ""
#define FLAQ_WIFI_PASSWORD ""
#define FLAQ_HOSTNAME "flaq-xiao"
#define FLAQ_AP_PASSWORD "flaq-air"

// Grove 8-Channel I2C Hub TCA9548A. Tous les capteurs du projet ont des
// adresses différentes : les huit canaux peuvent donc rester ouverts.
#define FLAQ_I2C_MUX_ENABLED 1
#define FLAQ_I2C_MUX_ADDRESS 0x70
#define FLAQ_I2C_MUX_CHANNEL_MASK 0xFF

// Fuseau Europe/Paris avec changements automatiques heure d'été/hiver.
#define FLAQ_TIMEZONE "CET-1CEST,M3.5.0/2,M10.5.0/3"
#define FLAQ_NTP_SERVER_1 "pool.ntp.org"
#define FLAQ_NTP_SERVER_2 "time.cloudflare.com"

// Broches XIAO ESP32S3.
#define FLAQ_BUZZER_PIN D1
#define FLAQ_OLED_BUTTON_PIN D7
#define FLAQ_VENTILATION_BUTTON_PIN D6

// Le WSP2110 est optionnel : si D0/A0 reste non connecté ou si sa lecture est
// invalide, le firmware publie simplement une mesure HCHO indisponible.
#define FLAQ_WSP2110_ENABLED 1
#define FLAQ_WSP2110_PIN D0
#define FLAQ_SD_CS_PIN D2
#define FLAQ_SD_SCK_PIN D8
#define FLAQ_SD_MISO_PIN D9
#define FLAQ_SD_MOSI_PIN D10

// Périodes de fonctionnement.
#define FLAQ_SAMPLE_INTERVAL_MS 10000UL
#define FLAQ_SGP40_INTERVAL_MS 1000UL
#define FLAQ_OLED_TIMEOUT_MS 20000UL
#define FLAQ_BUTTON_DEBOUNCE_MS 35UL
#define FLAQ_SD_FLUSH_INTERVAL_MS 60000UL

// Seuils de l'indice intérieur FLAQ. Ils restent modifiables ici sans toucher
// au reste du firmware.
#define FLAQ_CO2_YELLOW_PPM 800.0f
#define FLAQ_CO2_ORANGE_PPM 1000.0f
#define FLAQ_CO2_RED_PPM 1500.0f
#define FLAQ_CO2_RESET_PPM 1400.0f

#define FLAQ_VOC_YELLOW_INDEX 120.0f
#define FLAQ_VOC_ORANGE_INDEX 180.0f
#define FLAQ_VOC_RED_INDEX 220.0f
#define FLAQ_VOC_RESET_INDEX 200.0f

// WSP2110 : estimation indicative en ppm d'après la courbe typique Seeed.
// Le module doit être étalonné individuellement après au moins 120 h de chauffe.
#define FLAQ_WSP2110_R0_RATIO 34.28f
#define FLAQ_WSP2110_VC_VOLTS 5.0f
// Avec le pont conseillé 10 kΩ (haut) + 20 kΩ (bas), Vadc/Vsortie = 2/3.
#define FLAQ_WSP2110_DIVIDER_RATIO 0.6666667f
// Une entrée libre suit presque entièrement les pull-up/pull-down internes.
#define FLAQ_WSP2110_PRESENCE_DELTA_MV 1000UL
#define FLAQ_WSP2110_VALID_READINGS 3

// Seuils pédagogiques configurables, dans la plage indicative du WSP2110.
// Ils ne correspondent pas à des seuils réglementaires certifiés.
#define FLAQ_HCHO_YELLOW_PPM 1.0f
#define FLAQ_HCHO_ORANGE_PPM 2.0f
#define FLAQ_HCHO_RED_PPM 5.0f
#define FLAQ_HCHO_RESET_PPM 4.5f

#define FLAQ_PM25_YELLOW_UGM3 15.0f
#define FLAQ_PM25_ORANGE_UGM3 25.0f
#define FLAQ_PM25_RED_UGM3 50.0f
#define FLAQ_PM25_RESET_UGM3 45.0f

#define FLAQ_PM10_YELLOW_UGM3 45.0f
#define FLAQ_PM10_ORANGE_UGM3 50.0f
#define FLAQ_PM10_RED_UGM3 100.0f
#define FLAQ_PM10_RESET_UGM3 90.0f

// Seuil distinct pour la moyenne glissante PM2.5 sur 24 heures.
#define FLAQ_PM25_24H_LIMIT_UGM3 15.0f
#define FLAQ_PM25_24H_RESET_UGM3 13.5f

// Une alerte doit être confirmée par ce nombre de mesures consécutives.
#define FLAQ_CONFIRMATION_SAMPLES 3

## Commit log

2026-07-25 Add EASE air quality station project
    [Assemblage CO2-MH-Z16.SLDASM, Assemblage PM2.5 HM 3301.SLDASM, Assemblage recepteur Lora.SLDASM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]
2026-07-25 Remove individual sensor prototypes from repository
    [Assemblage CO2-MH-Z16.SLDASM, Assemblage PM2.5 HM 3301.SLDASM, boite arduino R4 basse usb .STL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]
2026-08-18 Add XIAO station and reorganize test project
    [Assemblage recepteur Lora.SLDASM, Fix capt CO2 V2.SLDPRT, Fix capt CO2 V2.STL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]
2026-08-22 Update FLAQ XIAO prototype and documentation
    [Assemblage1^ensemble_xiao - couvercle_xiao-1.STL, Assemblage1^ensemble_xiao - logo-1.STL, boitier bas.SLDPRT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]
2026-09-04 Update XIAO firmware and enclosure files
    [Assemblage1^ensemble_xiao - couvercle_xiao-1.STL, Assemblage1^ensemble_xiao - logo-1.STL, Pièce1.SLDPRT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]
2026-09-29 Rename project to FLAQ and publish XIAO station only
    [Assemblage recepteur Lora.SLDASM, BOSS-EXTRUDE14_10_.step.SLDPRT, BOSS-EXTRUDE14_11_.step.SLDPRT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]
2026-10-03 Fix Arduino toolchain location after project rename
2026-10-10 Mettre à jour les illustrations, la vidéo et les modèles SolidWorks
2026-10-10 Corriger le pont WSP2110 et expliquer le condensateur de filtrage

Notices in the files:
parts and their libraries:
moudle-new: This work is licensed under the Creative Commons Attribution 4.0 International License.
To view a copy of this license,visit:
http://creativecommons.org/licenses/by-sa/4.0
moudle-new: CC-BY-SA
